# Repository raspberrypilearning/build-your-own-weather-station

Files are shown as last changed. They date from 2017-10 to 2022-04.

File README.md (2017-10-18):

# build-your-own-weather-station
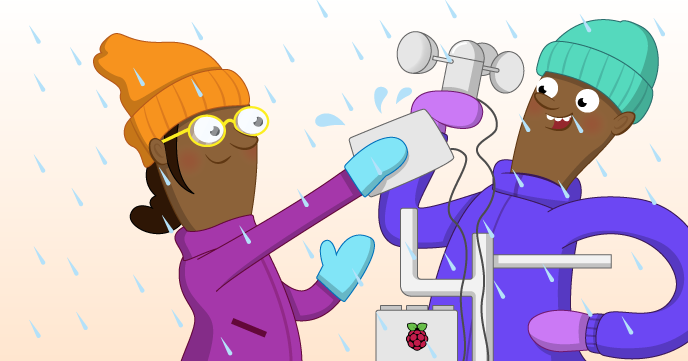
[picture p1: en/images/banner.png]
build-your-own-weather-station

Find the project online at [projects.raspberrypi.org/en/projects/build-your-own-weather-station](https://projects.raspberrypi.org/en/projects/build-your-own-weather-station)

## Contributing
See [CONTRIBUTING.md](CONTRIBUTING.md)
## Licence
 See [LICENSE.md](LICENSE.md)

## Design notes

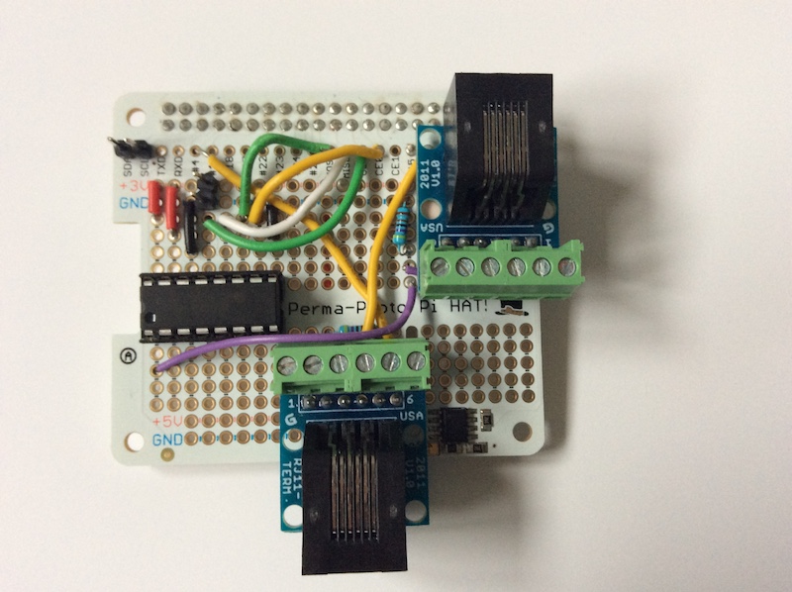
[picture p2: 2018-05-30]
en/images/BYO_HAT_front.JPG

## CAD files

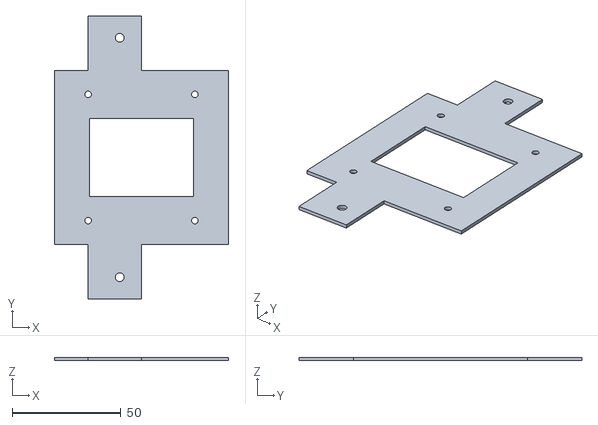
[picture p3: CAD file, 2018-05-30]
en/resources/BYOWS-bracket.stl
80.0 x 130.0 x 1.50

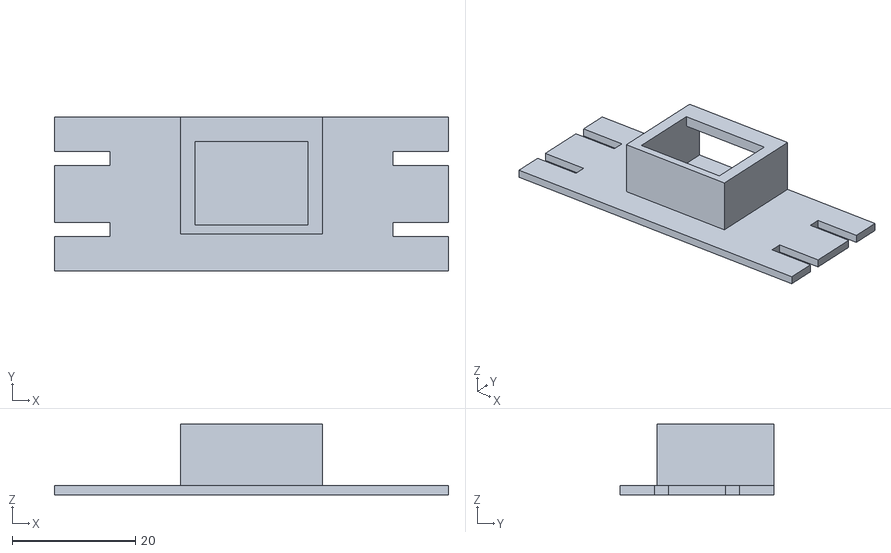
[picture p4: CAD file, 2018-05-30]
en/resources/bme280holder.stl
64.0 x 25.0 x 11.5

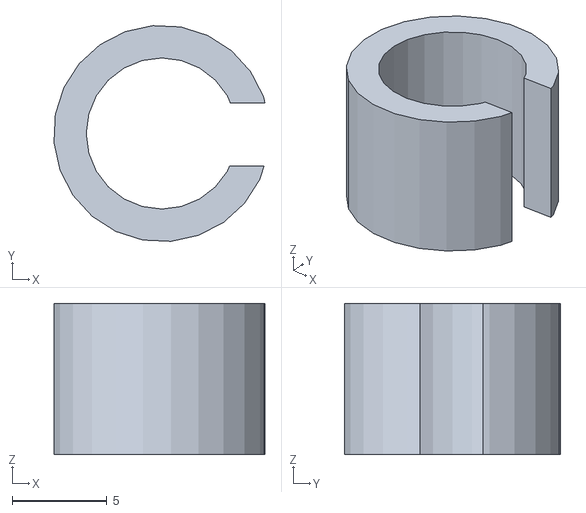
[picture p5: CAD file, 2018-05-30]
en/resources/BYOWS-grom.stl
11.1 x 11.4 x 8.00

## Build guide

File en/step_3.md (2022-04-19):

## Humidity, temperature and pressure

The BME280 sensor is a digital sensor that can measure temperature, humidity, and atmospheric pressure. It is available in a number of breakout boards from popular manufacturers such as Adafruit and SparkFun. This guide assumes you have the Adafruit package, but the instructions should be applicable to most versions. One thing to check is that the I2C address is correct: for the Adafruit models it is 0x77 (as shown in the code below), but other versions can have different addresses (0x76 is a common alternative).

### Wiring up the sensor

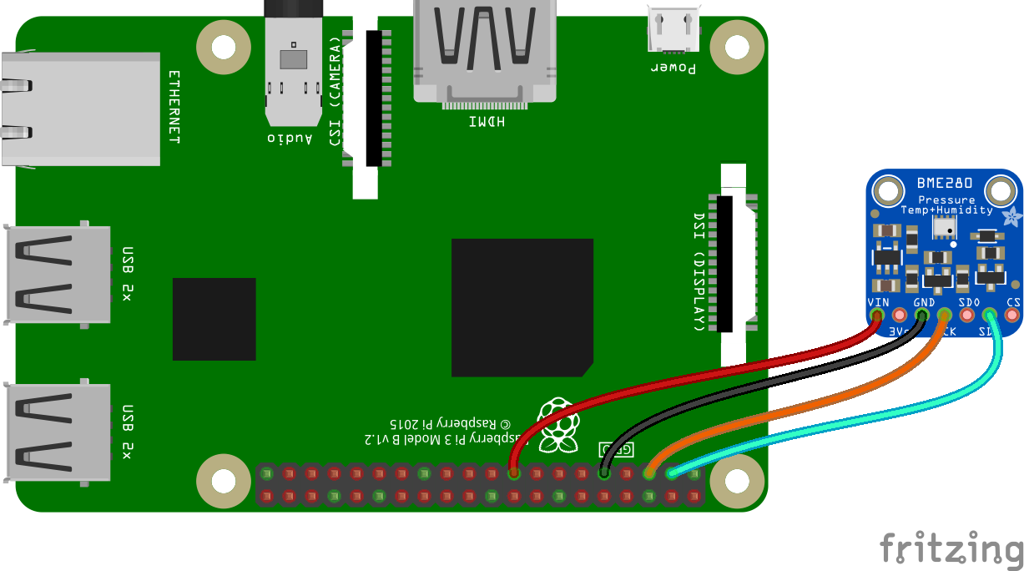
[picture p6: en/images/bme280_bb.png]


- Connect up the sensor to your Pi as shown in the diagram above.

| Pi GPIO | BME280  |
|---|---|
| 17 (3V3) | Vin |
| 6 (Gnd) | Gnd|
| 3 (SDA) | SDA (SDI) |
| 5 (SCL) | SCL (SCK)|

Some other breakout boards may have other pins (such as SDO or CSB), but those are not generally needed.

- Open IDLE.

[[[rpi-gui-idle-opening]]]

- Create a new Python file, save it as `/home/username/weather-station/bme280_sensor.py`. Replace `username` with your username on your Raspberry Pi, and add the following code to it:

```python
import bme280
import smbus2
from time import sleep

port = 1
address = 0x77 # Adafruit BME280 address. Other BME280s may be different
bus = smbus2.SMBus(port)

bme280.load_calibration_params(bus,address)

while True:
    bme280_data = bme280.sample(bus,address)
    humidity  = bme280_data.humidity
    pressure  = bme280_data.pressure
    ambient_temperature = bme280_data.temperature
    print(humidity, pressure, ambient_temperature)
    sleep(1)
```

- Now test the code: while the code is running, exhale onto the sensor. You should see the humidity values (and possibly the temperature values) increase. When you've finished testing, terminate the code by typing <kbd>ctrl+c</kbd> in the Python shell.

Once you're happy that the sensor is recording sensible values, you can go on to modify the program so that it is ready to be used as part of the whole weather station operation later.

- Replace the `while True` loop with a function called `read_all()` that returns the humidity, pressure, and temperature readings, in that order.

---hints---
---hint---
Functions are declared with the `def` keyword:

```python
def read_all():
```

---/hint---
---hint---
Add a line to sample the data from the I2C device. Then return the temperature, pressure, and humidity components of that reading.

---/hint---
---hint---
Your file should look like this:
```python
import bme280
import smbus2
from time import sleep

port = 1
address = 0x76
bus = smbus2.SMBus(port)

bme280_load_calibration_params(bus, address)

def read_all():
    bme280_data = bme.sample(bus,address)
    return bme280_data.humidity, bme280_data.pressure, bme280_data.temperature

```
---/hint---
---/hints---

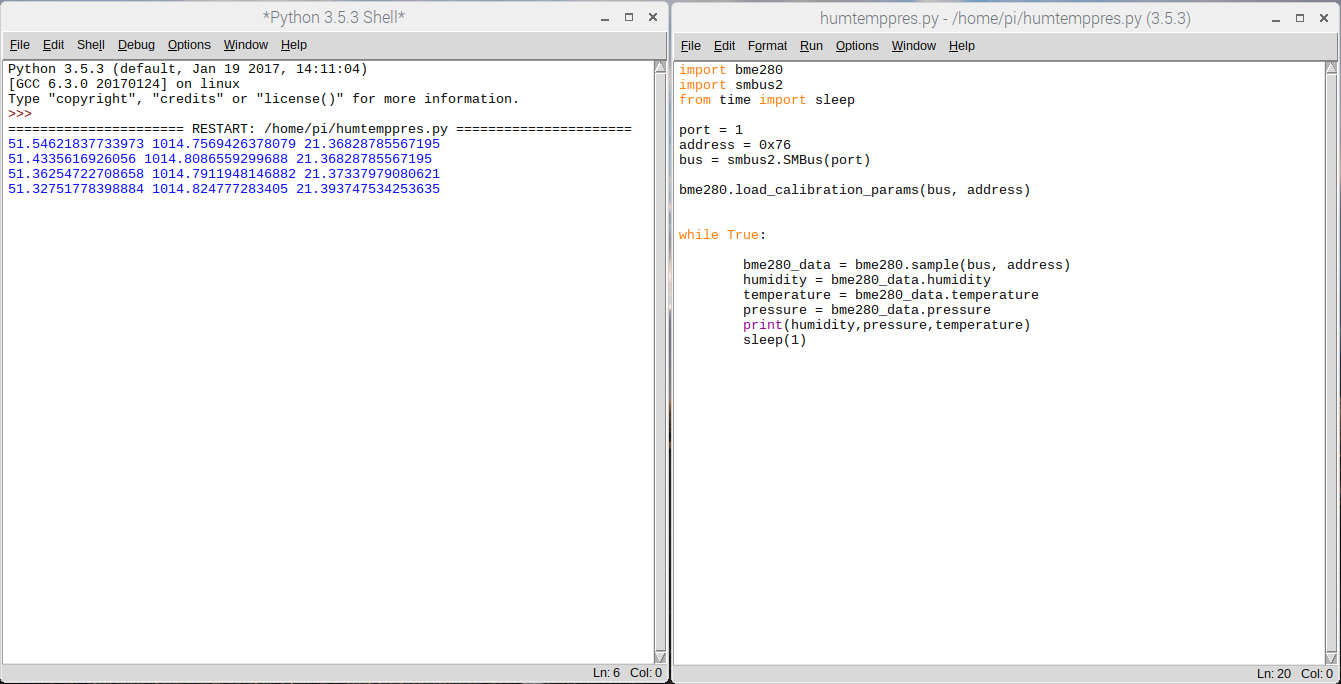
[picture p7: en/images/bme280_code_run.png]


## Ground temperature

The BME280 will report the air temperature, but this can be significantly warmer than the ground, particularly if it is frosty. A thermal probe stuck into the soil is a useful supplemental temperature measurement and can be used to indicate the presence of ice/frost in winter. The Dallas DS18B20 temperature sensor comes in many forms including a waterproof thermal probe version, and this is the sensor used on the Oracle Raspberry Pi Weather Station.

### Wiring up the sensor

- Normally the DS18B20 comes with three bare wires, so the easiest way to prototype and test the sensor is to use PCB mount screw terminal blocks that can also be plugged into breadboards. Add your DS18B20 to your circuit as shown in the diagram below. Note that you are setting up 3.3V and Ground rails along the side of the breadboard. These will be used later when you add extra sensors into the circuit.

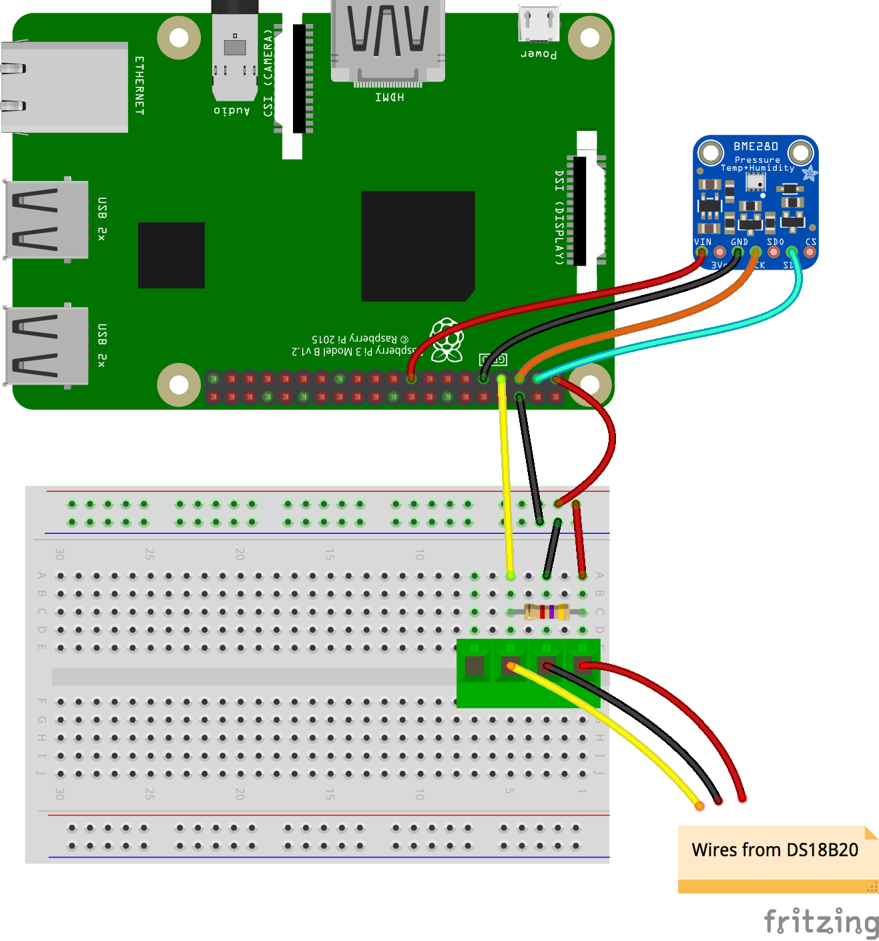
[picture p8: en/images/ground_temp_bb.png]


- Open the file `/boot/config.txt`:

```bash
sudo nano /boot/config.txt
```
 - Edit it by adding the line below at the bottom:

 ```bash
 dtoverlay=w1-gpio
 ```
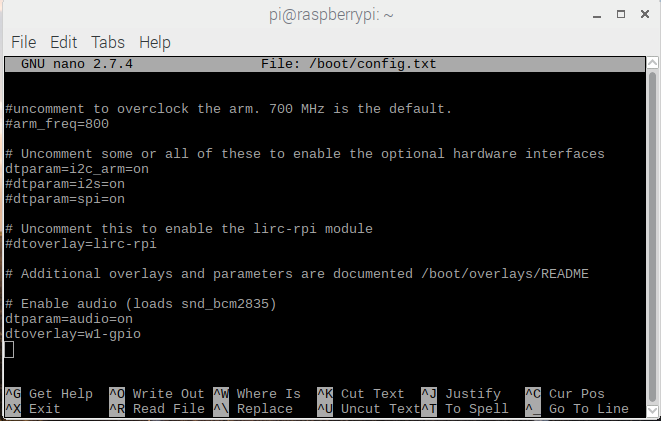
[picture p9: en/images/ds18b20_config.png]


- Then open `/etc/modules`.

```bash
sudo nano /etc/modules
```

- Add the lines below at the bottom of the file:

```bash
w1-gpio
w1-therm
```
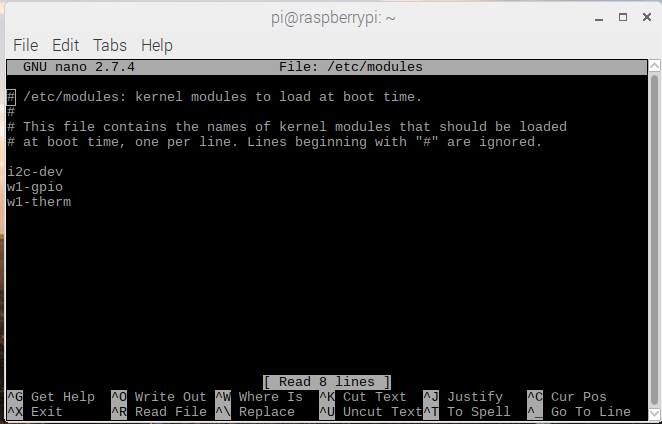
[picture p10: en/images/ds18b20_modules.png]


- Reboot the Raspberry Pi.

- Open the file `/home/pi/weather-station/ds18b20_therm.py` in IDLE and run it. You should see the temperature printed out in the Python shell window.  

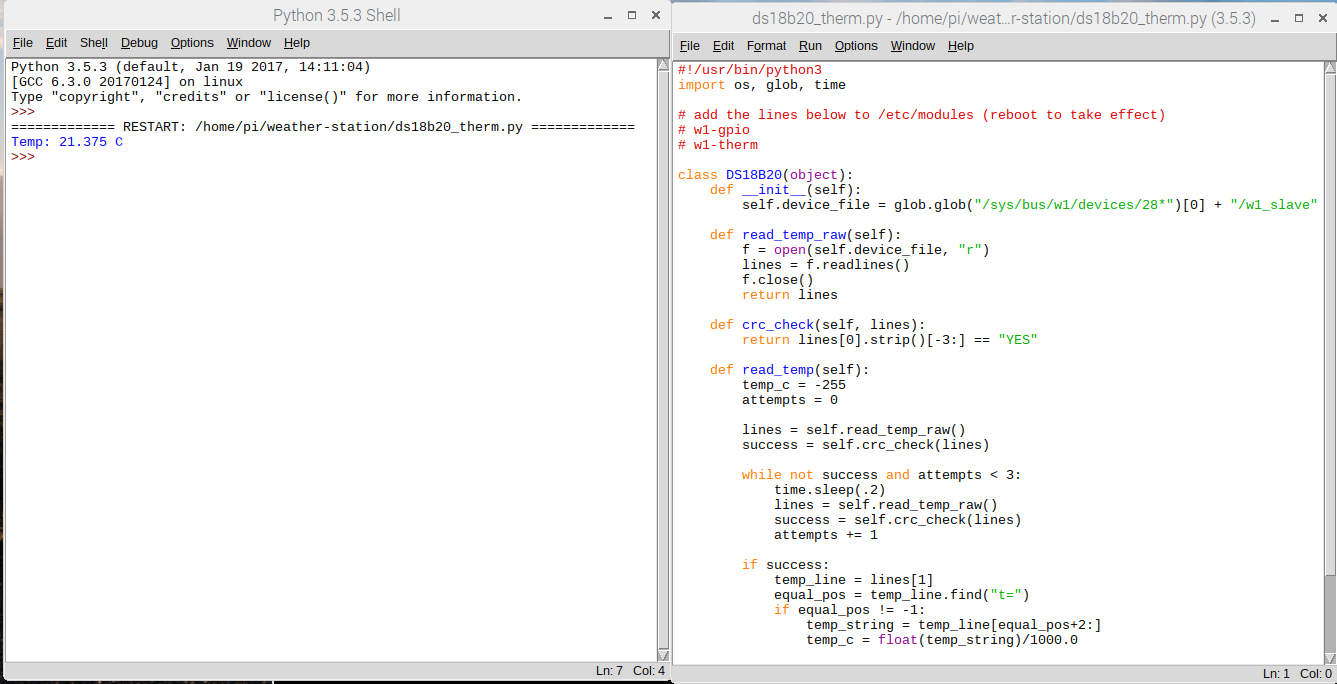
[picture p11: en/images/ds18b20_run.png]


- Put the probe into a glass of cold water and re-run the program. The new temperature reported should be lower (unless you were working in a very cold room in the first place!).

### Troubleshooting

- If you are unable to take readings from the DS18B20 sensor, check that the wires from the probe are securely connected to the screw terminals and that you have modified the `/etc/modules` and `/boot/config.txt` correctly.

+ Open a terminal window and type:

```bash
ls /sys/bus/w1/devices/
```
You should see two files listed. If these are not shown, then recheck your wiring.

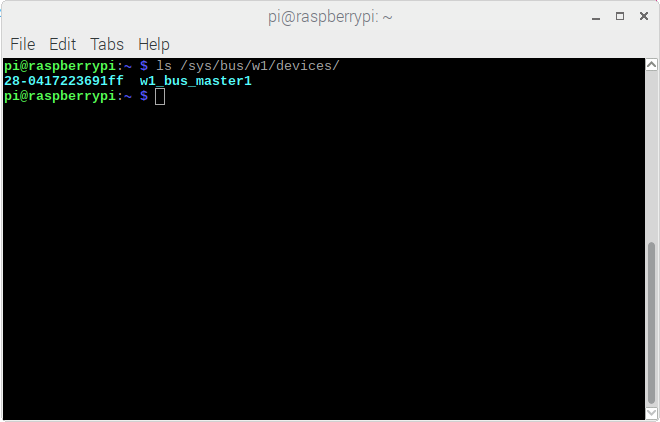
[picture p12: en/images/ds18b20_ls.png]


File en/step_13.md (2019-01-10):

## Challenge: add custom sensors
- Now you've got your weather station up and running, why not add some more sensors? You have seven free pins on the MCP3008 ADC, so you could incorporate more analog sensors!

- How about a light meter or UV sensor? How could you keep it watertight?

- Or maybe you could add a lightning detector — there are a few commercial boards available for doing this.

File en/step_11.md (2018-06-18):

## Assembling everything for outdoors

### Wireless connectivity

So that your weather station can upload data to somewhere you can view and analyse it, it will need some form of internet connection. Using WiFi is typically the easiest way to do this, but you can use the ethernet connection if that works better for your location. There's a guide about setting up wireless connectivity on your Raspberry Pi [here](https://www.raspberrypi.org/documentation/configuration/wireless/), and some special hints for getting wireless access working with a weather station are [here](https://www.raspberrypi.org/learning/weather-station-guide/outside2.md).

### Make a weather station HAT

You should now have a working weather station prototype on a breadboard. If you are happy keeping your weather station in this form, then click through to to the *Keeping your weather station dry* section.

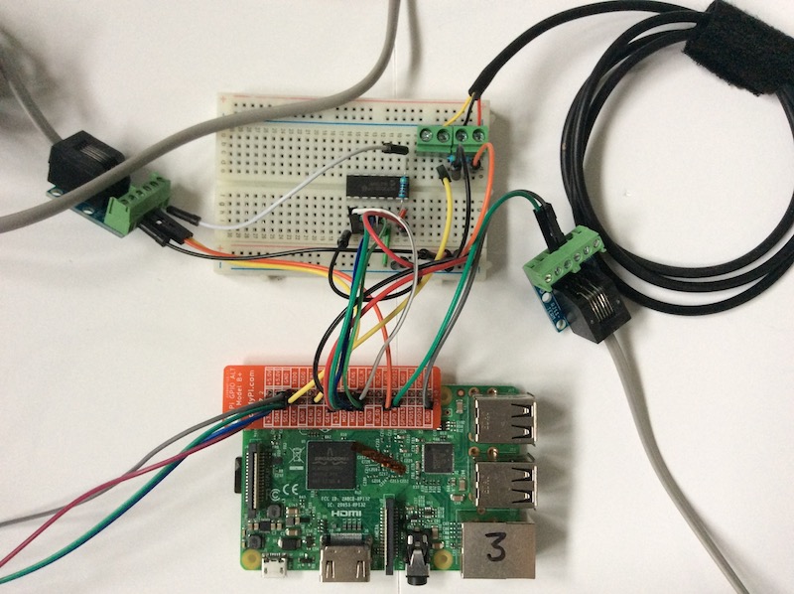
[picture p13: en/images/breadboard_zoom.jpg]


For a more robust, long-term installation, or if you don't have room for a breadboard in your enclosure, you can construct a weather station HAT (hardware attached on top) for your Pi. This will involve some soldering, and if you've never soldered before, we have a [great resource plus video tutorial](https://projects.raspberrypi.org/en/projects/getting-started-with-soldering) to get you started.

Note that to really be able to call it a HAT, your board should include a programmed EEPROM. The Adafruit Perma-Proto HAT kit does come as a variant with an EEPROM so this is definitely something you could do, although we won't cover the procedure in this guide. A good place to start is this [github repository](https://github.com/raspberrypi/hats){:target="_blank"}, or this [MagPi article](https://www.raspberrypi.org/magpi/make-your-own-hat/){:target="_blank"}.

If you are going to solder your project using the recommended components, make sure to read through all the instructions before starting. The assembly is a little tricky, and it will taken even an experienced maker two to four hours.

As usual, there is more than one way to do this this. You could design a layout for stripboard (also known as veroboard).



Soldering stripboard connections can be trickier than the 'through-hole' type you may be familiar with from assembling other digital making kits. However, prototyping HATs for Raspberry Pi are also available and these have plated through hole (PTH) connections that are much easier two work with.

The circuit diagram below shows a possible design for a weather station HAT using the Adafruit Perma-Proto HAT Kit. You can lay things out differently if you have used alternative components.

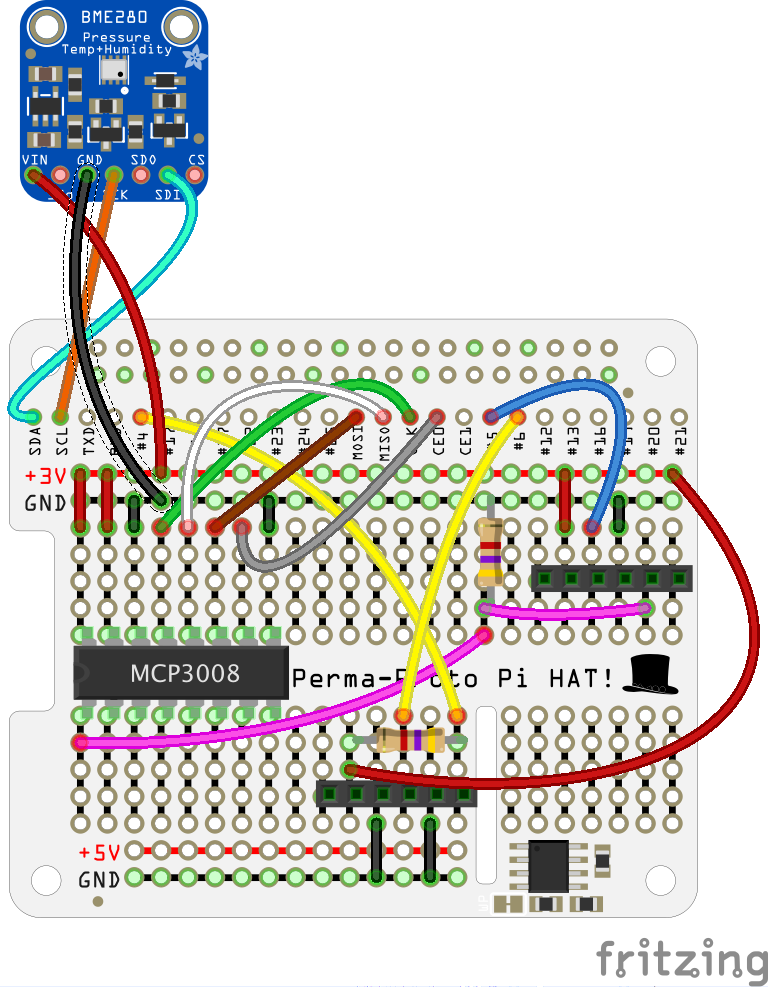
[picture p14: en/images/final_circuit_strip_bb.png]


#### Things to note about this circuit diagram

- To avoid cluttering the view, the six pins for each of the two RJ11 breakout boards are shown as female headers.

- Interpreting this diagram requires a slightly different approach to building a breadboard circuit. Because the PTH connections go all the way through the board, you can actually (and usefully) route and connect wires and components on either side.

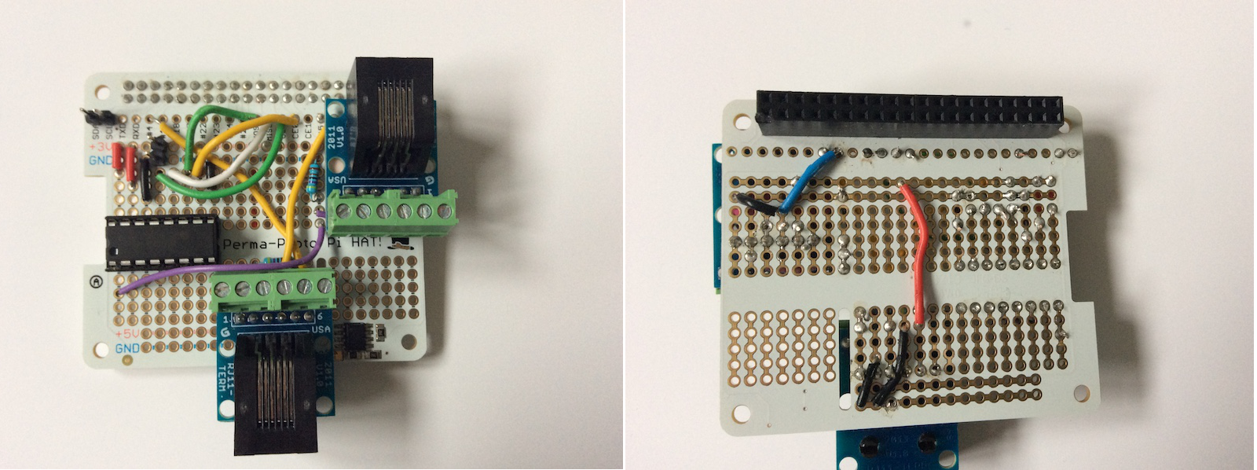
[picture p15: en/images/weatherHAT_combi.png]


In the photo above, you can see that two 2-pin male connectors have been used for the BME280 sensor. This method makes assembly easier, because the sensor should be housed in a separate enclosure. However, you could solder the wires connecting the sensor directly to the HAT (after threading them through the water-tight glands or grommets used).

## Assembly

You are recommended to assemble and test things one step at a time, checking each connection to a weather sensor once you've added it to the board.

- First of all, solder the 40-pin header onto the Adafruit board.

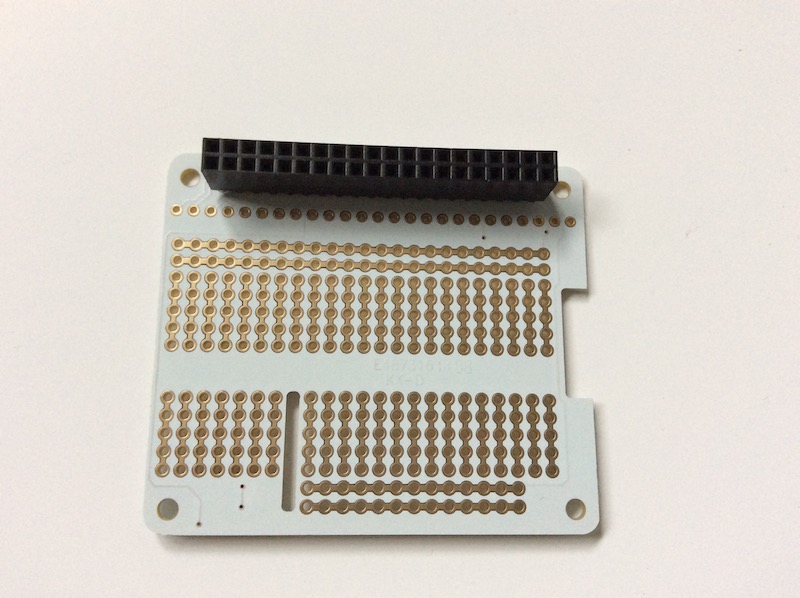
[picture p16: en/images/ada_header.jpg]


- Solder on two 2-pin male headers, one across the SCL and SDA connections in the top left-hand corner, and one across the **3V** and **GND** rails.

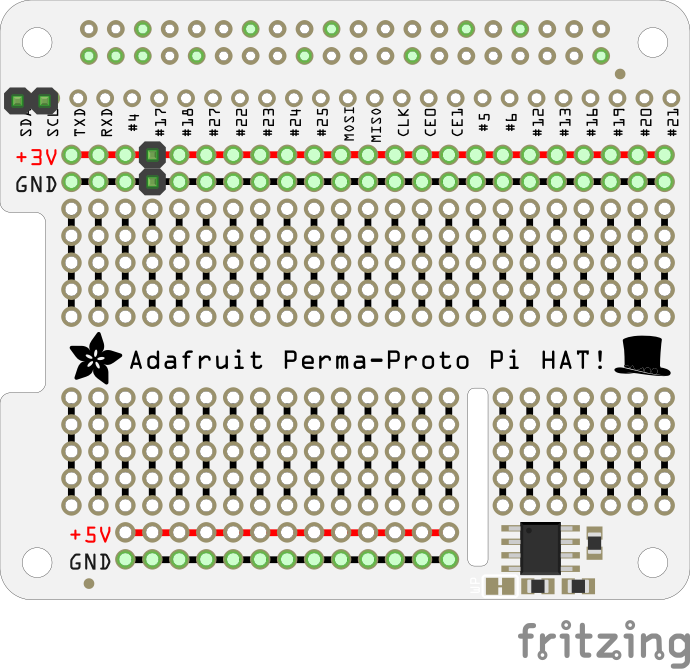
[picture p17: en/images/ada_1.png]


- Connect the BME280 sensor to these pins and place the HAT on the Pi.

- Boot the Pi and test that the BME280 sensor works using the `bme280_sensor.py` code that you wrote earlier.

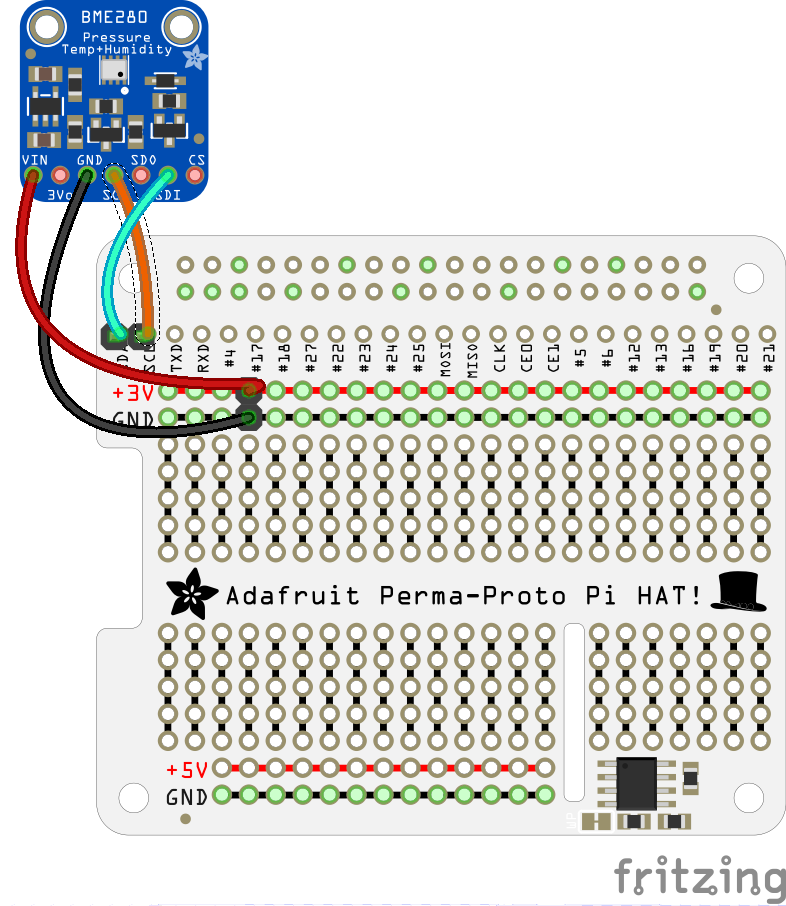
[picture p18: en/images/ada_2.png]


Next, add connections for the DS18B20 probe. On the breadboard you used screw terminals. You could use them again on the proto-board, but you may have noticed that one of the RJ11 breakout boards has some unused pins. You can be sneaky and make use of the unused screw terminals to save space: the rainfall gauge only uses the two centre pins of the connector, so the two outer ones on either side are free.

- Power down the Pi and remove the HAT.

- Solder a 4.7K ohms resistor in the bottom area as shown. Your RJ11 breakout board will need to sit just above this, so try to seat the resistor so that it is flat against the top of the Adafruit board and not poking upwards.

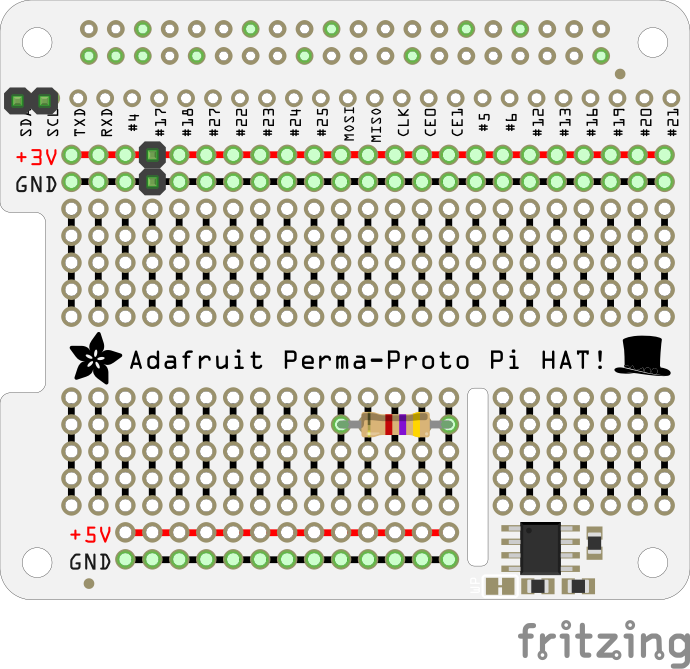
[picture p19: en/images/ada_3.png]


- Now add two connections to the bottom **GND** rail using small lengths of wire.

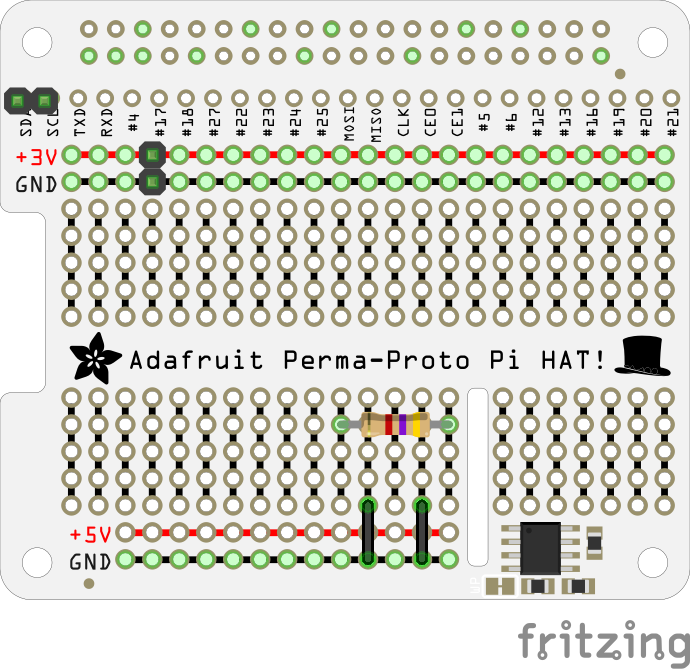
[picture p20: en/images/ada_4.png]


- Then add longer wires to connect the GPIO pin breakout connections (**GPIO 4, 6**) and the **3V** rail. Once again, try to keep these as low as possible where the RJ11 breakout board will sit. As mentioned earlier, you can solder the wires through from the bottom of the HAT rather than across the top. As long as the correct holes are connected together, it doesn't matter which side of the HAT you use.

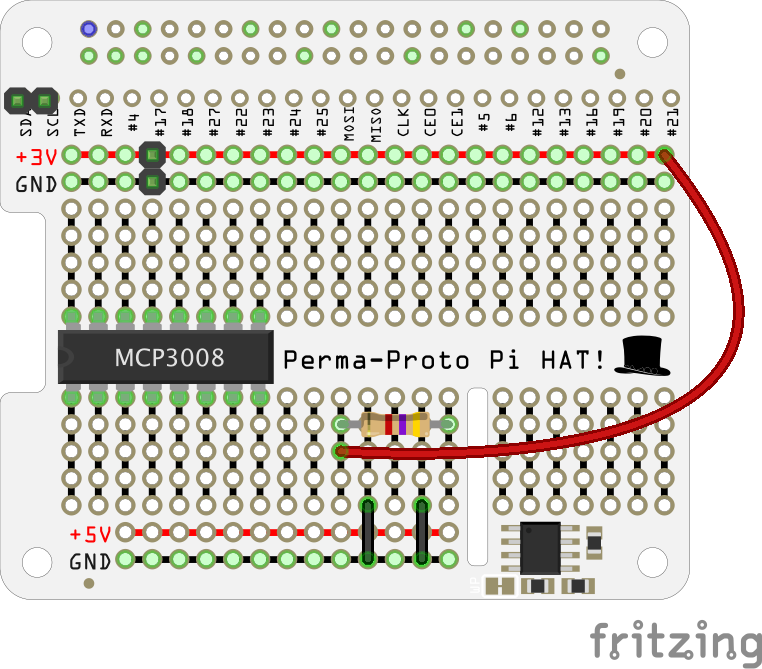
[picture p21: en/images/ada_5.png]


The connection to the **3V** rail will pass through a 'busy' part of the board if it goes over the top, so this is a good choice to put it on the rear.

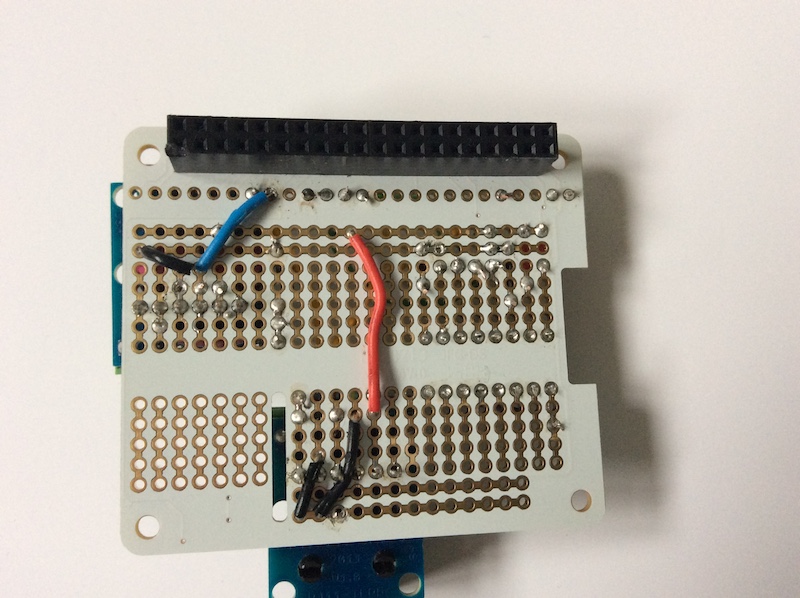
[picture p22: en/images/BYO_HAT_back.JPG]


- Now prepare the RJ11 breakout board. Some of the pre-soldered parts of these breakout boards can be quite spiky. To avoid these peaks of solder from causing shorts when placed onto the Adafruit board, carefully trim them with side cutters. It is also a good idea to then cover them with a small strip of insulating tape.

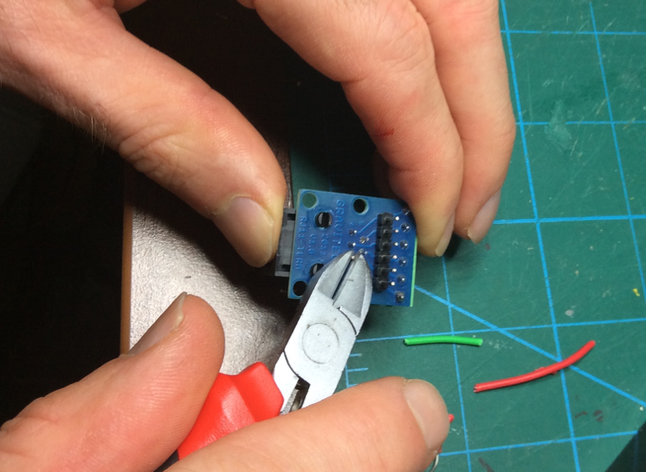
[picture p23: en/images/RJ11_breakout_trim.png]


- With some versions of the smaller boards, the male pins you need for connection to the Adafruit board are supplied separately. You may have to solder them onto the breakout board first. Make sure the shortest end of the pin is the part that you solder on, as the longer end is the part that you'll solder onto the Adafruit board.

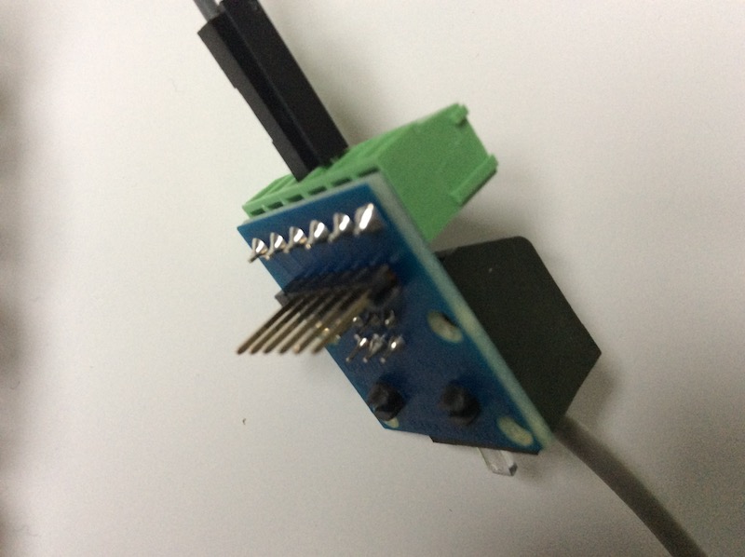
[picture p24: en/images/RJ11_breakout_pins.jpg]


- Solder the RJ11 breakout board in place, making sure that the pins slot into the correct place on the Adafruit board. Be careful not to melt the plastic on the RJ11 socket. The pins from the breakout board are quite long and will make contact with the HDMI port on the Raspberry Pi when the HAT is in place. Therefore, you should either trim them or use some insulating tape on the top of the HDMI port to prevent a short circuit.

- Connect the DS18B20 sensor to the screw terminals on the breakout board as shown below.

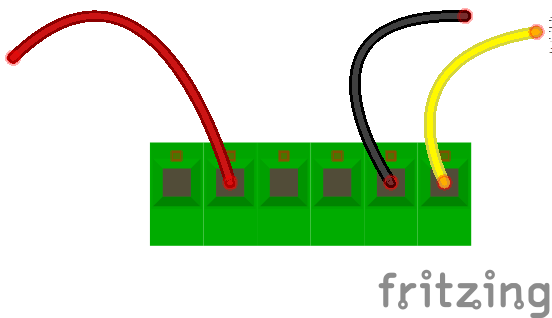
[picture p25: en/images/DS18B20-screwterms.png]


- Carefully remount the HAT on the Pi. Before powering up the Pi, check that none of the soldered connections on the bottom of the Adafruit board are touching the top components on the Pi. If they are, trim the wires or pins in question.   

- Power up the Pi and test your DS18B20 sensor using the `ds18b20_therm.py` script.

- Connect the rain gauge's RJ11 connector to your HAT.

- Test that the rain gauge works using the `rainfall.py` scripts you've written.

Now you need to add the MCP3008 ADC. While you can solder the IC directly onto the Adafruit board, it is much better to use a DIP/DIL IC socket. This reduces the chance of damage to the IC and also makes it easier to swap components out in future.

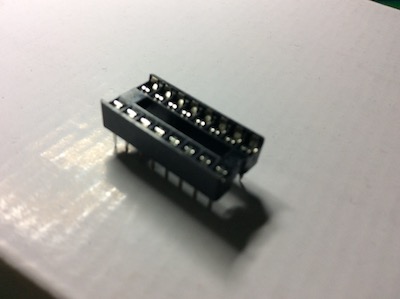
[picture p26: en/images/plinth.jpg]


- Remove the HAT and solder the socket onto the Adafruit board, in the position shown by the MCP3008 IC in the diagram.

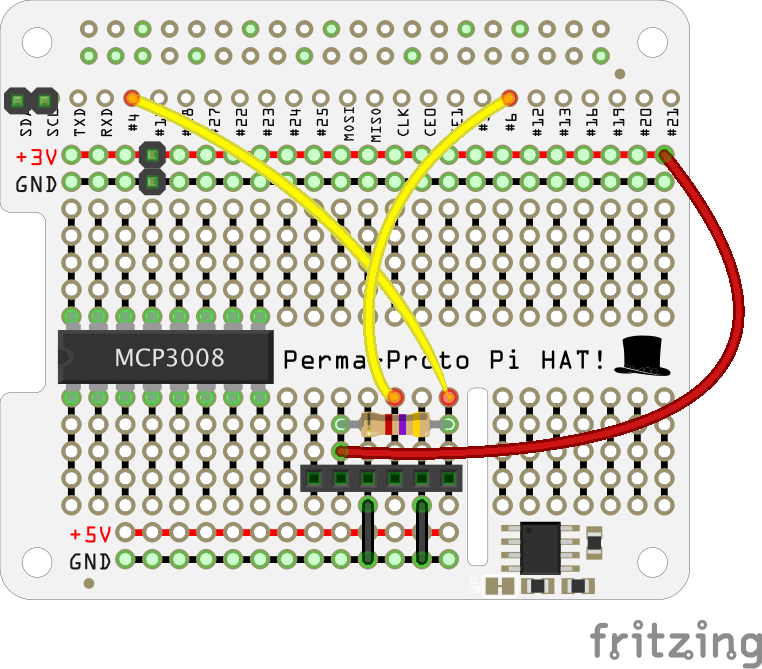
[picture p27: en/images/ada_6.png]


- Now use five short strips of wire to make connections to the **3V** and **GND** rails for the IC and the second RJ11 breakout board.

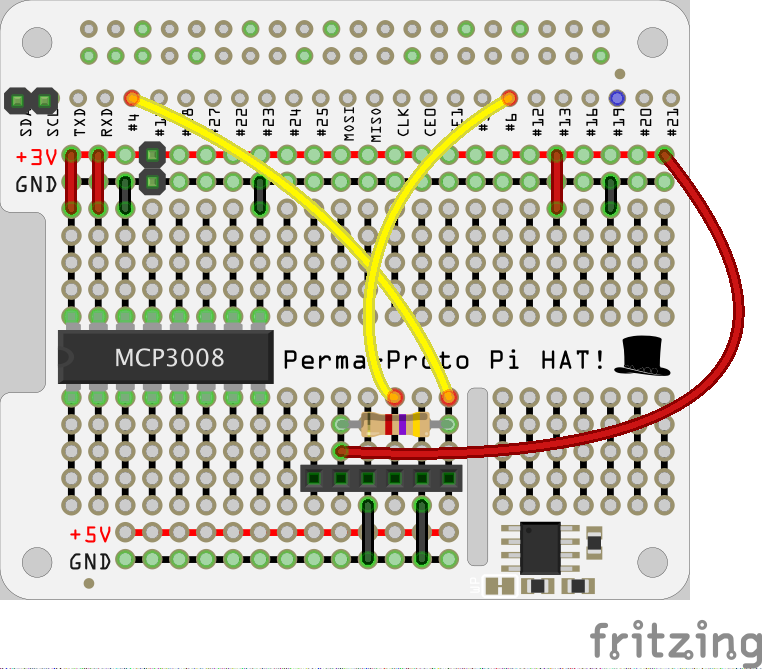
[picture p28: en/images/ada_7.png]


- Using some longer wire strips, add in the other connections to the GPIO pins. You can use either the front or the back of the board to route these connections, although soldering the GPIO ends near the black plastic of the female header on the back can be trickier than on top.

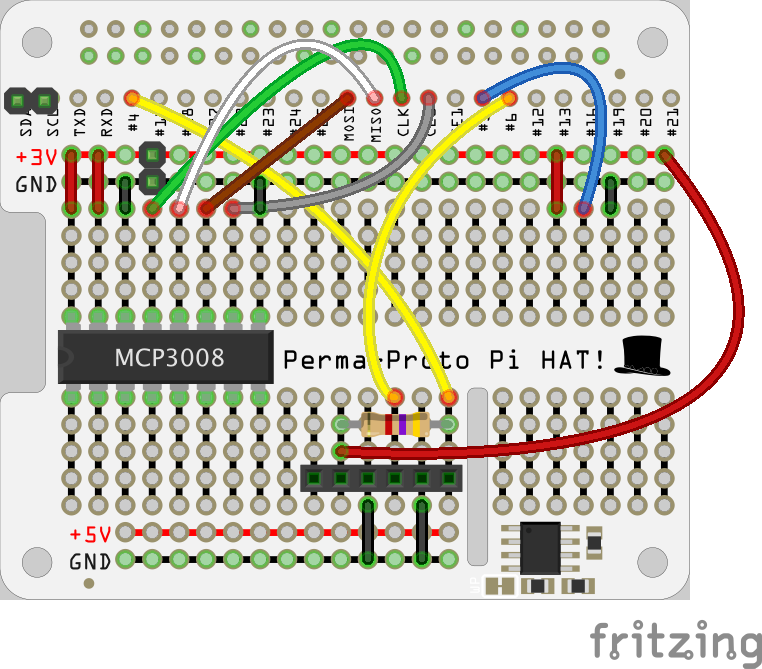
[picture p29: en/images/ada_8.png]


- Add two final wires for the wind vane part of the circuit.

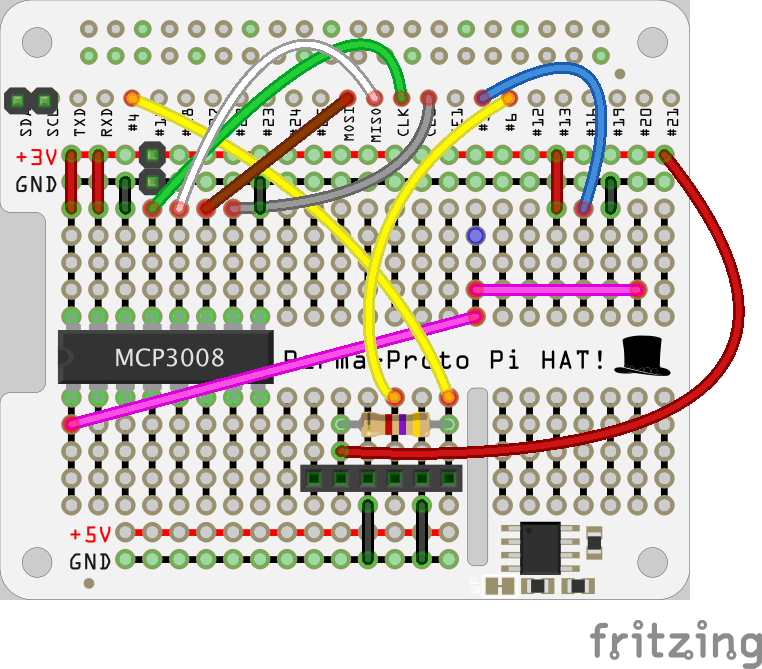
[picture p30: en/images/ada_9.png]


- Then solder on the second 4.7K ohms resistor.

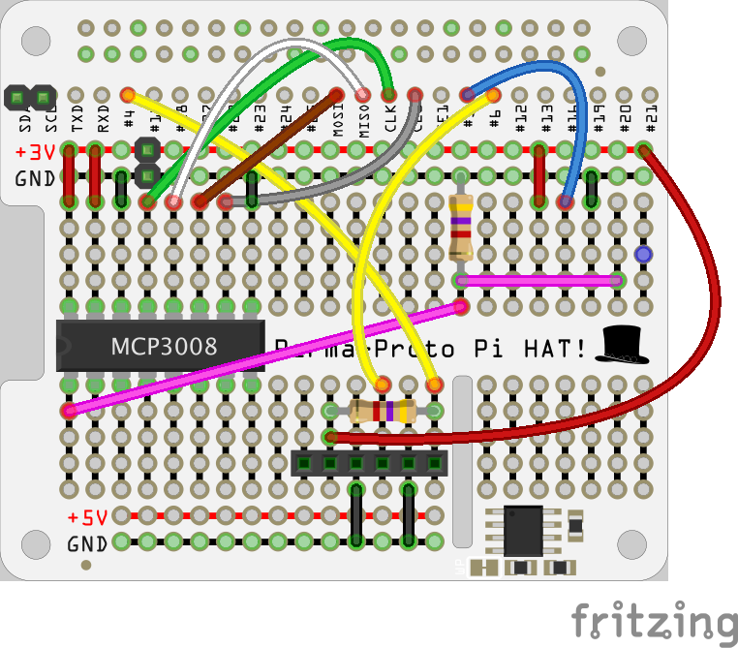
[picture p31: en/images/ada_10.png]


- The final step is to add the second RJ11 breakout board, remembering to ensure that no short circuits are caused by spiky or long pins protruding from the bottom of the board.

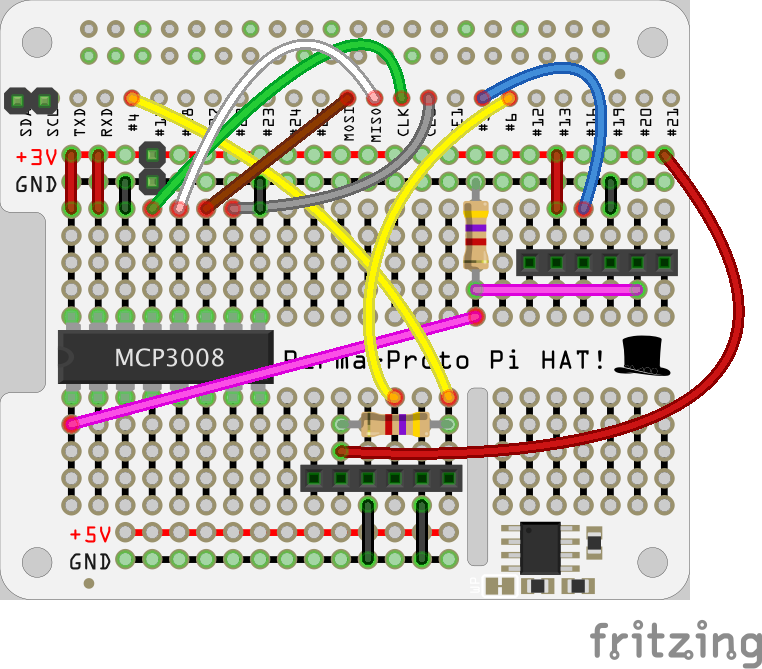
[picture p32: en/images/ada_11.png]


- Carefully insert the MP3008 IC into the socket. You may need to gently bend the legs slightly so that they fit in without being crushed under the main body of the chip itself.

- Remount the HAT on the Pi again. Check that none of the soldered connections on the bottom of the Adafruit board are touching the top components on the Pi. Trim any wires or pins if they are.

- Plug in the RJ11 connector from the wind sensors and test them using the `wind_direction_byo.py` and `wind.py` scripts you wrote.

- You should now have a fully working weather HAT. Test it for a while with the full program that you completed in the previous step.

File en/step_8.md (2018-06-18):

## Wind direction

### Wind vanes
Wind vanes show the direction the wind is coming from, not where it's going. This can be a little confusing in the beginning, because the arrows on most TV weather maps show the opposite. A wind vane works because wind exerts force on its vertical blade, which rotates to find the position of least wind resistance; this position is aligned with the direction of the oncoming wind.

### How your wind vane works
Like the rain gauge or anemometer, the wind vane used here also has reed switches and a rotating magnet, but it is more complex and works in a completely different way.

If you look inside the recommended wind vane, you'll see eight reed switches arranged like the spokes of a wheel.

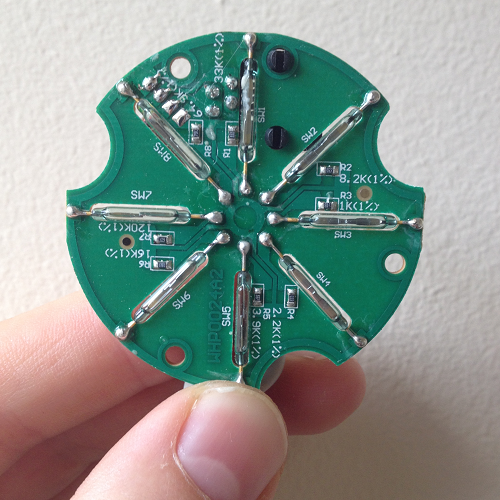
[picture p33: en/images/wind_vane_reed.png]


There are also eight **resistors** in the wind vane, and as the magnet rotates, different reed switches will open and close and thus switch their corresponding resistor in and out of the circuit.

### The role of the resistors
Resistors are small components that resist/reduce the flow of electrical current without stopping it. Resistors can have different **resistance** values, reported in ohms Ω; those with low resistance let almost all current through, while those with high resistance let very little current through. The most common uses for resistors are protecting components from being damaged by currents that are too high, or dividing voltage between different parts of a circuit.

Each of the eight resistors has a different value, which you should see printed in white next to it (e.g. you can see 8.2K on the right). This allows the wind vane to have 16 possible combinations of resistance, since the magnet can close two neigboring reed switches when it's positioned halfway between them. You can find more information in the [data sheet](https://www.argentdata.com/files/80422_datasheet.pdf).

Most wind vanes you can connect to a Pi work in a similar way, so if you have a different model, consult its data sheet to find the values for the resistors.

### Measuring the resistance
In order to read the wind direction from the vane, you'll need to be able to measure the resistance produced by the sensor and convert that into an angle value. There are several steps in this process.

Instead of measuring the resistance value directly, it is actually much easier to record a **voltage** from the wind vane that varies according to which combination of resistors is currently switched into the circuit. This means you'll be measuring an **analogue** value: the wind vane will continuously report a **range** of voltages. By contrast, the anemometer simply reports a 'HIGH' or 'LOW' voltage — all or nothing, meaning it sends a **digital** signal.

[[[generic-theory-analogue-digital]]]

### Measuring analogue voltages with a Raspberry Pi

Unlike an Arduino, which has analogue inputs, the Raspberry Pi only has digital inputs. So to be able to interpret an analogue signal, you need a special component called an analogue-to-digital convertor (ADC).

A popular and versatile ADC is the MCP3008. It is a 16-pin integrated circuit (IC) with eight analogue inputs and can easily be used with a breadboard. It is a 10-bit ADC, meaning it has 2^10 = 1024 possible output values: e.g. for a reference voltage of 5V, the smallest change in voltage that the MCP3008 can detect is 5V/1024 = 4.88mV.

Now you can measure a changing analog signal using the MCP3008, you can use another clever circuit to produce a voltage that varies with the resistance of the wind vane.

### Using a voltage divider

Voltage dividers are among the most fundamental circuits in electronics, and they're used to reduce a large voltage into a smaller one.  

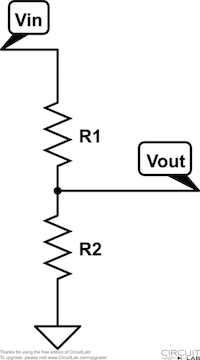
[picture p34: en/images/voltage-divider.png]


In the circuit above, the output voltage `Vout` can be calculated using the formula:

**`Vout = Vin * R2/(R1 + R2)`**

So by varying the values of `R1` and `R2`, you can reduce the input voltage `Vin` down to the output voltage `Vout`.

- Use this formula to create a new Python program called `voltage-divider.py` that contains a function `voltage_divider` that calculates `Vout` for a given set of `R1`, `R2`, and `Vin`.

---hints---
---hint---
To start off, create a function definition that takes the three input values:

```python
def voltage_divider(r1, r2, vin):
```
---/hint---
---hint---

Then add the formula.

```python
vout = (vin* r1)/(r1+r2)

```
---/hint---
---hint---

Finally, include a `return` statement. To make things easier to read, round the answer to three decimal places.
```python
def voltage_divider(r1,r2,vin):
    vout = (vin* r1)/(r1+r2)
    return round(vout,3)
```
---/hint---
---/hints---

- Test your function to make sure it provides the right answer for a selection of input values. For example, when `R1 = 33K ohms, R2 = 10K ohms` and a reference voltage of `Vin = 5V`, the function should return an answer of `3.837V`.

```python
print(voltage_divider(33000,10000,5.0))
```

Now returning to the circuit, if you imagine that `R2` is actually the resistance of some kind of variable resistor (a light-dependent resistor, for example), then by measuring `Vout`, we can calculate `R2` as long as we know `R1`. The wind vane acts like a variable resistor, so you can use a voltage divider circuit to measure its resistance value at any given time.

First of all, you need to find the best value for `R1` to use.

### Designing a voltage divider

You may have noticed that the second page of the wind vane data sheet contains a voltage divider circuit diagram and a table that lists angle, resistance, and voltage. The value quoted for `R1` in this diagram is 10K ohms. However, this circuit uses a `Vin` reference voltage of 5V. The logic levels on a Raspberry Pi are 3.3V, so these `Vout` figures are not quite right for what you need.

- Using the list of resistances from the datasheet and the voltage divider formula, write a small Python program called `vane_values.py` to calculate the new values for a 3.3V `Vin` with a `R1` resistance of 10K ohms.

---hints---
---hint---
To start off, create a list that contains all the resistances of the vane:

```python
resistances = [33000, 6570, 8200, 891,
               1000, 688, 2200, 1410,
               3900, 3140, 16000, 14120,
               120000, 42120, 64900, 21880]
```
Then loop through this list, calculating the output voltage for each value. You can use the `voltage_divider` function you wrote earlier for this part.  
---/hint---
---hint---

To loop through the list and print out each value, you could use the code:

```python

for x in range(len(resistances)):
    print(resistance[x])
```
This can be expanded to include the calculation too.
---/hint---
---hint---

A complete solution, including rounding the values to three decimal places, is:
```python
resistances = [33000, 6570, 8200, 891,
               1000, 688, 2200, 1410,
               3900, 3140, 16000, 14120,
               120000, 42120, 64900, 21880]

def voltage_divider(r1,r2,vin):
    vout = (vin* r1)/(r1+r2)
    return round(vout,3)

for x in range(len(resistances)):
    print(resistances[x],voltage_divider(10000,resistances[x],3.3))
```
---/hint---
---/hints---

Using the value of `R1 = 10K ohms` works well when the reference voltage is 5V, but you should see that some of the possible voltages are quite close together when using 3.3V. By using a smaller value for R1, you can optimise the separation between the different voltages that correspond to the resistance values produced by the vane.

- Use your `vane_values.py` code to test alternative values for `R1`. Remember that only certain standard resistance values are available.

The most common in the range you'll need are (in K ohms):
+ 1
+ 1.2
+ 1.5
+ 1.8
+ 2.2
+ 2.7
+ 3.3
+ 4.7
+ 5.6
+ 6.8
+ 8.2

You should find that 4.7K ohms is a good value for the recommended wind vane.

- Now you know the value for `R1` in the voltage divider circuit, you can wire everything up to your ADC and the Pi.

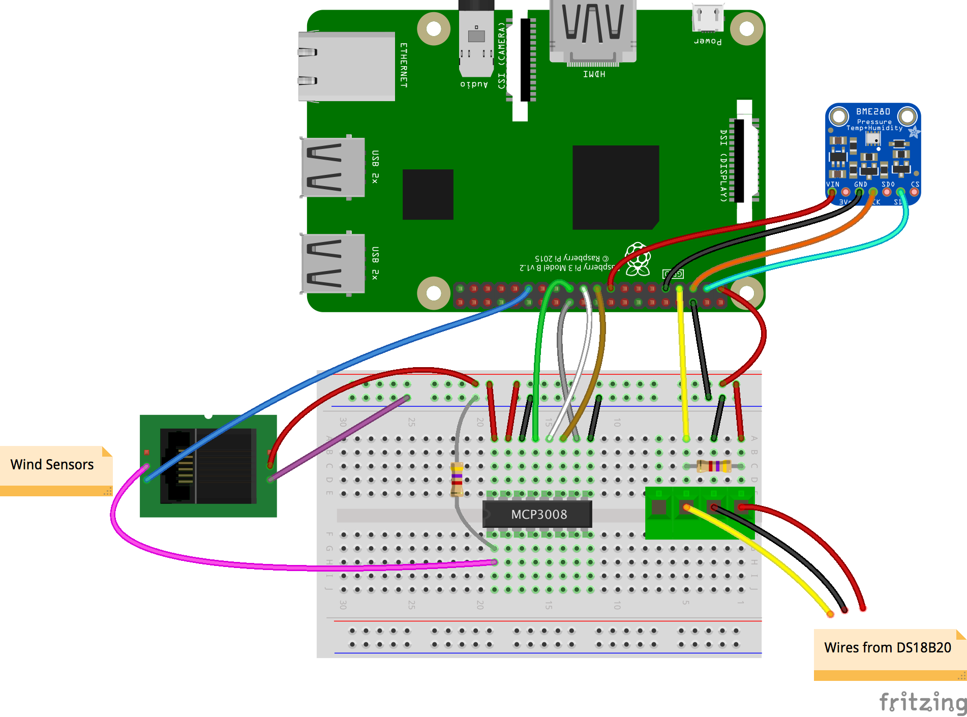
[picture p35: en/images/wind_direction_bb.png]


Reading values from an MCP3008 ADC is very easy, thanks to the `gpiozero` library.

```Python
from gpiozero import MCP3008
import time
adc = MCP3008(channel=0)

print(adc.value)
```
This code will read channel 0 of the ADC and print its value scaled to between 0 and 1. To find the actual analog voltage that's recorded, multiply the value by the reference voltage supplied to the ADC.

- You need to test that your circuit is able to discriminate between the various angular positions of the wind vane. Create a small python program called `/home/pi/weather-station/wind_direction_byo.py` to count the different values produced by your circuit when the vane is rotated.  

---hints---
---hint---
Use the `gpiozero` library to create a MCP3008 instance:

```Python
from gpiozero import MCP3008
import time
adc = MCP3008(channel=0)
```

---/hint---
---hint---

Then create a list to hold all the values:

```python
values = []
```
Then add a loop to repeatedly read voltages from the ADC and add the read values to the list **if they aren't already present in it**.
---/hint---
---hint---

A complete solution is:
```Python
from gpiozero import MCP3008
import time
adc = MCP3008(channel=0)
count = 0
values = []
while True:
    wind =round(adc.value*3.3,1)
    if not wind in values:
        values.append(wind)
        count+=1
        print(count)
```
---/hint---
---/hints---

- Run your code while rotating the wind vane. Your should see the number of unique voltages seen so far printed out in the Python shell.

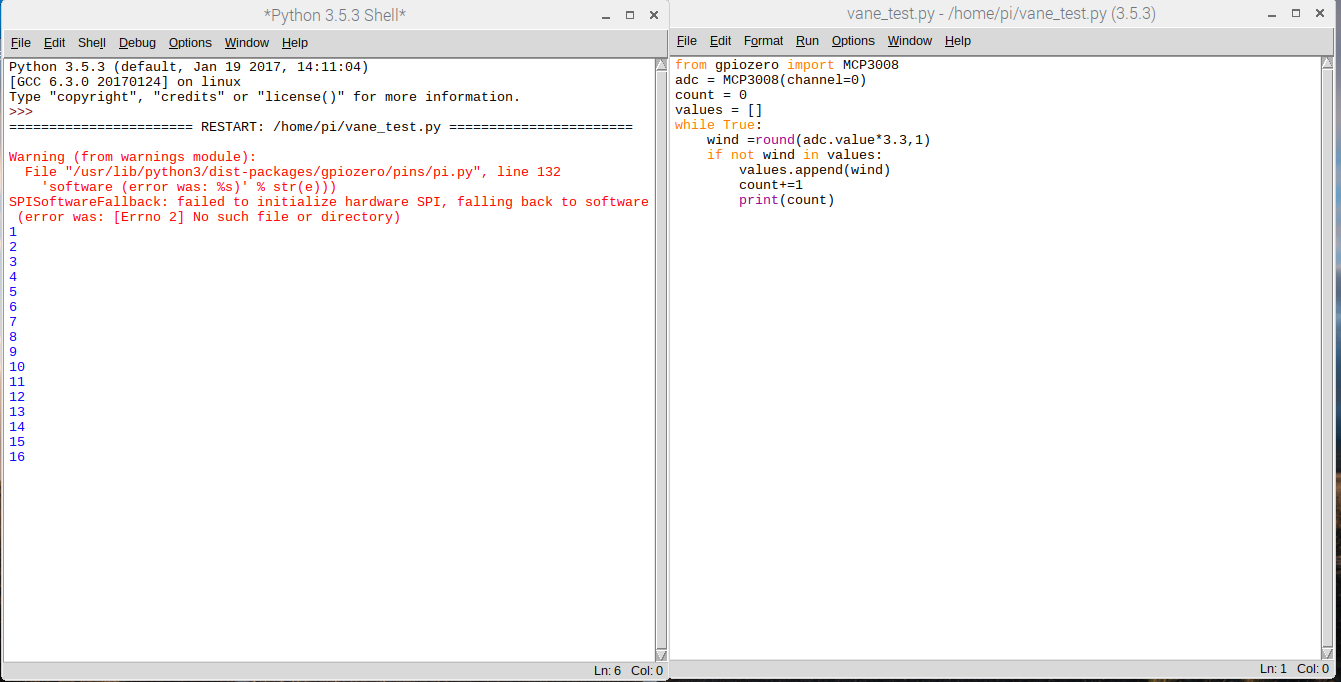
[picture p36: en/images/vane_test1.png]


- You may also see some red text warning you about 'SPISoftwareFallback'. You can safely ignore this, but if you'd rather not have the warning appear again in future, click on the Raspberry Pi menu icon and select **Preferences > Raspberry Pi Configuration**. Then enable **SPI** in the Interfaces tab, and reboot your Pi.

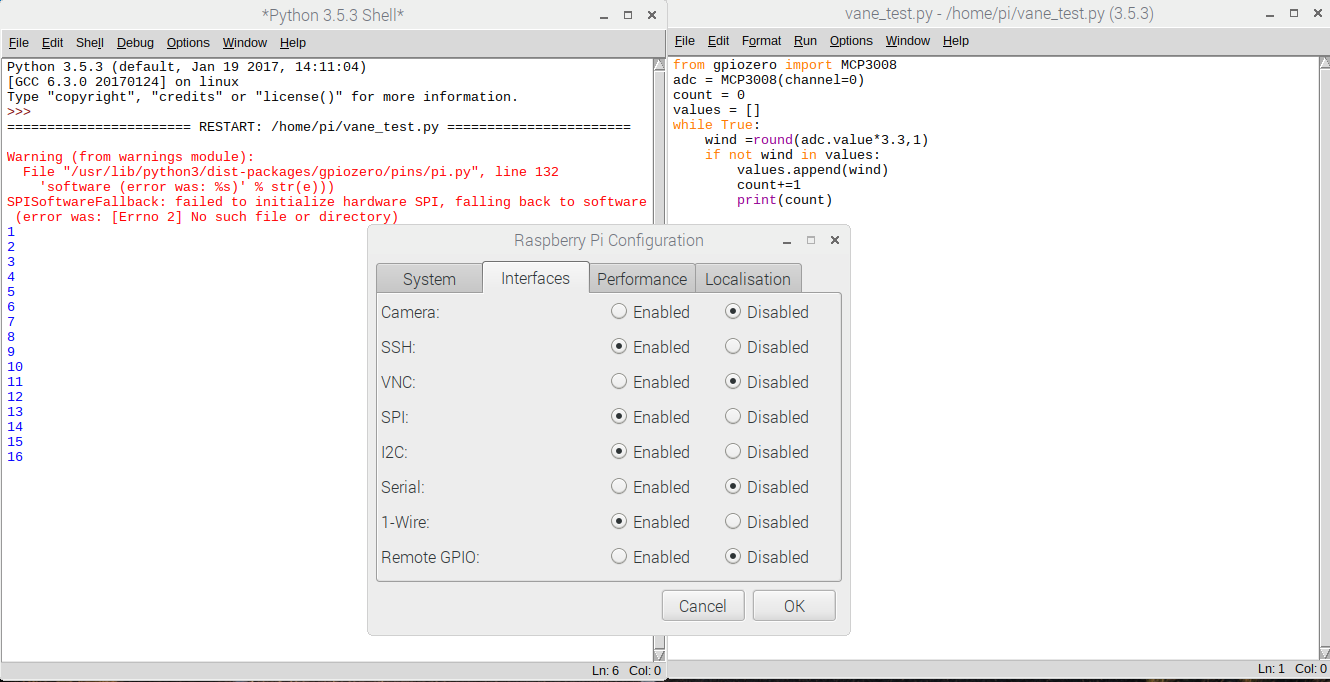
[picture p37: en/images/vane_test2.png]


- If everything is accurate to a very high level of precision, then you should be able to measure no more than 16 unique voltages. However because the ADC may record a rising or falling voltage, you may be able to generate a few more values through slow jiggling of the vane.  

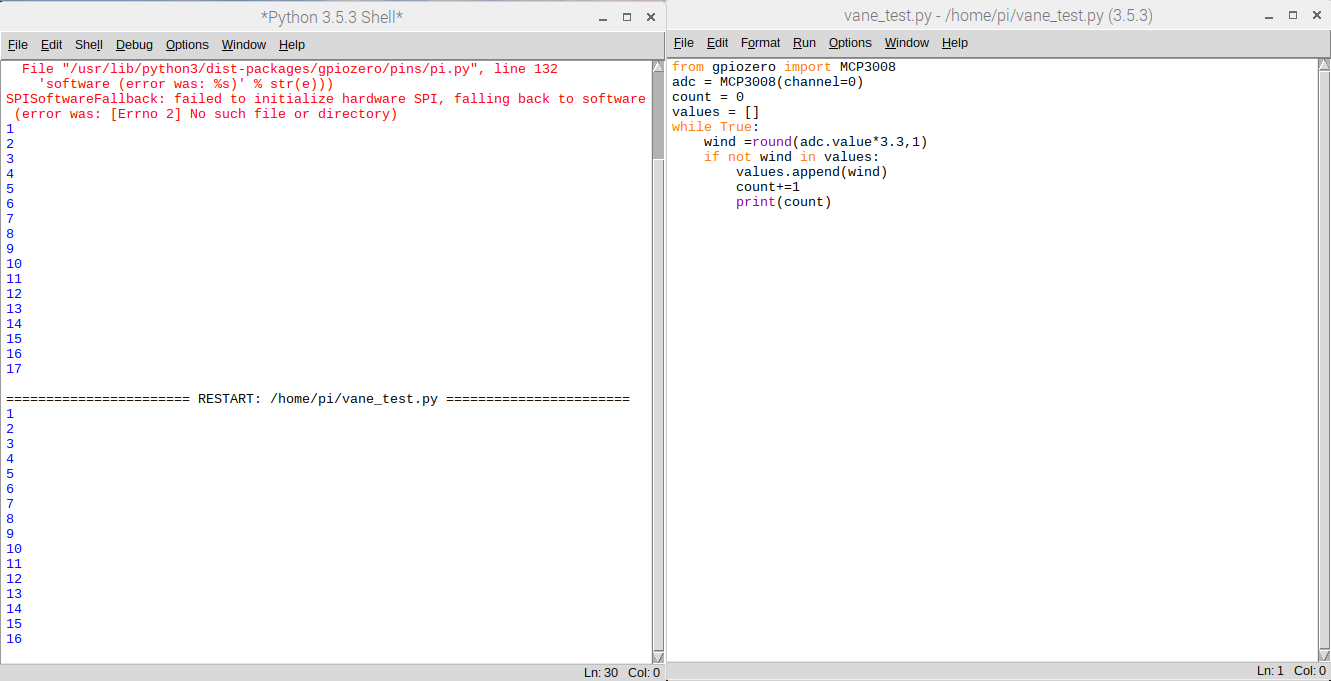
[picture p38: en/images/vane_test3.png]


- Modify your code to include a list of the possible correct values and check each reading from the ADC against this list. Have your code print a helpful message for each reading that indicates whether it was one of the correct values or not.

---hints---
---hint---
Add a list of possible values, all rounded to one decimal place. You can use your `voltage_divider` code to produce this list.

```Python
volts = [0.4, 1.4, 1.2, 2.8,
         2.9, 2.2, 2.5, 1.8,
         2.0, 0.7, 0.8, 0.1,
         0.3, 0.2, 0.6, 2.7]
```

---/hint---
---hint---

Then use an `if...else` conditional statement to test if the value from the ADC is in the `volts` list.
---/hint---
---hint---

A complete solution is:
```Python
from gpiozero import MCP3008
import time
adc = MCP3008(channel=0)
count = 0
volts = [0.4, 1.4, 1.2, 2.8,
         2.9, 2.2, 2.5, 1.8,
         2.0, 0.7, 0.8, 0.1,
         0.3, 0.2, 0.6, 2.7]
while True:
    wind =round(adc.value*3.3,1)
    if not wind in volts:
        print('Unknown value: ' + str(wind))
    else:
        print('Match: ' + str(wind))
```
---/hint---
---/hints---

The final step is to convert the readings from the vane into angles. At the heart of this is relationship between angle, resistance, and voltage. For every voltage value measured by the ADC, there is a corresponding resistance configuration of the wind vane, which in turn corresponds to the angle the vane's blade is at.

You can calculate the relationship between resistance and voltage using the `voltage_divider` function you wrote earlier. You can then look up the corresponding angle from the data sheet. So for example, if the ADC measures aa voltage of 0.4V, this corresponds to a resistance of 3.3K ohms, which maps to an angle of 0 (or 360) degrees.

- Modify your `wind_direction_byo.py` file and change your list of voltages into a Python **dictionary**: the voltages will be the **keys** and the corresponding angles will be the **values**.

[[[generic-python-key-value-pairs]]]

- Then change your `print` statements so that they display the angle of the vane.

---hints---
---hint---
Use the `voltage_divider` function to print the voltages and their corresponding resistance values. Then use the data sheet to look up the angles that map to those resistances.

---/hint---
---hint---
Your dictionary should look like this:
```python
volts = {0.4: 0.0,
         1.4: 22.5,
         1.2: 45.0,
         2.8: 67.5,
         2.7: 90.0,
         2.9: 112.5,
         2.2: 135.0,
         2.5: 157.5,
         1.8: 180.0,
         2.0: 202.5,
         0.7: 225.0,
         0.8: 247.5,
         0.1: 270.0,
         0.3: 292.5,
         0.2: 315.0,
         0.6: 337.5}
```
---/hint---
---hint---

A complete solution is:
```Python
from gpiozero import MCP3008
import time
adc = MCP3008(channel=0)
count = 0
values = []
volts = {0.4: 0.0,
         1.4: 22.5,
         1.2: 45.0,
         2.8: 67.5,
         2.7: 90.0,
         2.9: 112.5,
         2.2: 135.0,
         2.5: 157.5,
         1.8: 180.0,
         2.0: 202.5,
         0.7: 225.0,
         0.8: 247.5,
         0.1: 270.0,
         0.3: 292.5,
         0.2: 315.0,
         0.6: 337.5}
while True:
    wind =round(adc.value*3.3,1)
    if not wind in volts:
        print('unknown value ' + str(wind) + ' ' + str(volts[wind]))
    else:
        print('found ' + str(wind) + ' ' + str(volts[wind]))
```
---/hint---
---/hints---

You now have a Python program that reads the angle of the wind vane!

+ Test it by setting the wind vane into a certain position and checking that the code displays the correct value. Repeat for different positions.  

There is one last improvement you can make to the accuracy of your results, and that is to take multiple readings over a short period of time and then calculate the average value. The maths behind this is more complicated that you might think — you can read about it in detail [here](http://en.wikipedia.org/wiki/Directional_statistics){:target="_blank"}.

- Add the function below to your `wind_direction_byo.py` code.

```python
def get_average(angles):
    sin_sum = 0.0
    cos_sum = 0.0

    for angle in angles:
        r = math.radians(angle)
        sin_sum += math.sin(r)
        cos_sum += math.cos(r)

    flen = float(len(angles))
    s = sin_sum / flen
    c = cos_sum / flen
    arc = math.degrees(math.atan(s / c))
    average = 0.0

    if s > 0 and c > 0:
        average = arc
    elif c < 0:
        average = arc + 180
    elif s < 0 and c > 0:
        average = arc + 360

    return 0.0 if average == 360 else average
```
- To use it, you'll also need to import the `math` library by adding this line to the top of your file.

```python
import math
```

- Now, using a similar technique to how you checked for wind gusts in the previous step, modify your program so that in has a function `get_value()` that returns the average value for a given time period. This will make it easy to call this function from within your complete weather station code.

---hints---
---hint---

Store a number of wind direction values in a list, then use the `get_average()` function to calculate the average.

---/hint---
---hint---

You can use the `time.time()` function to accurately record values for a given time period.
---/hint---
---hint---

A complete solution is:

```Python
def get_value(length=5):
    data = []
    print("Measuring wind direction for %d seconds..." % length)
    start_time = time.time()

    while time.time() - start_time <= length:
        wind =round(adc.value*3.3,1)
        if not wind in volts: # keep only good measurements
            print('unknown value ' + str(wind))
        else:
            data.append(volts[wind])

    return get_average(data)
```
---/hint---
---/hints---

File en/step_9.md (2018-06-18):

## Rainfall

Most rain gauges measure precipitation in millimeters in height collected on one square metre during a certain time period.

The recommended rain gauge sensor supplied with the Raspberry Pi Weather Station kit is actually a simple mechanical device.

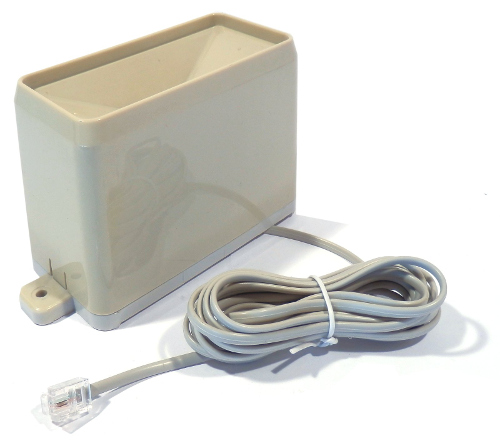
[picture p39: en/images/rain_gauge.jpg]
Rain Gauge


## How does it work?

You can investigate the rain gauge and how it works by removing the bucket. Gently squeeze the clips on either side; the lid should then pop off.

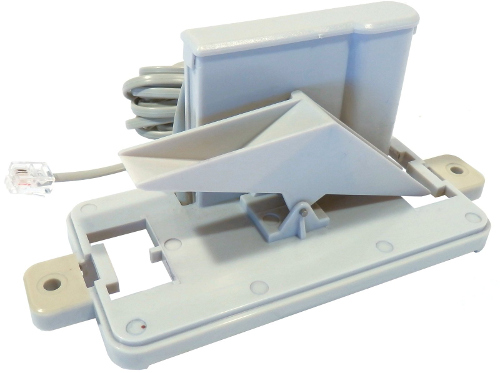
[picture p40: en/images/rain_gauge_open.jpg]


This rain gauge is basically a self-emptying tipping bucket. Rain is collected and channelled into the bucket. Once enough rainwater has been collected, the bucket will tip over, the water will drain out from the base, and the opposite bucket will come up into position.

The product [data sheet](https://www.argentdata.com/files/80422_datasheet.pdf){:target="_blank"} tells us that 0.2794 mm of rain will tip the bucket. You can multiply this by the number of tips to calculate the amount of rainfall. If you're using a different type of rain gauge, then you should consult the relevant data sheet or determine the volume of water required experimentally.

Typically these gauges are fitted with an RJ11 plug even though they only use two wires: one red and one green. Inside the ridge between the two buckets, you should see a small cylindrical magnet that points towards the back wall. Inside the back wall there's a *reed switch*.

The top of the back wall does come off if you want to see inside; just pull on the flat end gently and it should release. Inside there's a small circuit board that you can remove to examine. In the middle of it you will see the reed switch. Replace the circuit board and back wall lid before continuing.

When one of the buckets tips, the magnet passes the reed switch, causing it to close momentarily. So, just like with the anemometer, if you connect the rain gauge to a GPIO pin on the Raspberry Pi, you can treat it like a button and count the number of 'presses' to calculate rainfall.

## Connecting your rain sensor

- To test the rain gauge, you'll need to either remove the RJ11 connector and strip the wires, or make use of an RJ11 breakout board.

The Oracle Weather Station rain gauge is connected to **GPIO pin 6** (BCM), so for consistency, use the same pin for your device.

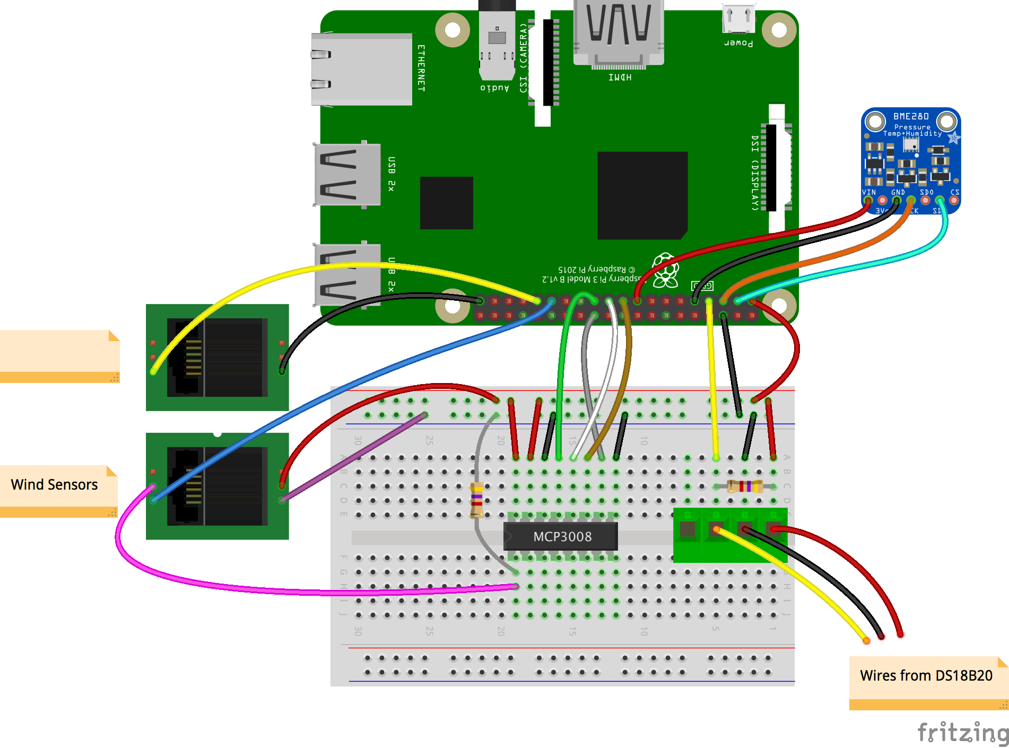
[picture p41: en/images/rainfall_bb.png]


- Using the code you wrote for the anemometer as a starting point, write a program called `/home/pi/weather-station/rainfall.py` to detect when the rain gauge bucket has tipped. It should print our a running count of how many bucket tips have occurred.

---hints---
---hint---
The `gpiozero` library provides an easy way to access button-like devices, and your bucket is connected to **GPIO 6**:

```python
from gpiozero import button
rain_sensor = Button(6)
```

---/hint---
---hint---
Create a function that is run whenever there's a bucket tip. You can assign a global variable as a counter to keep track of how many times the reed switch has been 'pressed'.
```python
def bucket_tipped():
    global count
    count = +=1
    print(count)
```
---/hint---
---hint---
Your program could look like this:

```python
from gpiozero import Button

rain_sensor = Button(6)
count = 0

def bucket_tipped():
    global count
    count = +=1
    print(count)

rain_sensor.when_pressed = bucket_tipped
```

---/hint---
---/hints---

Now that you can count bucket tips, you need to convert this into a height of water that equals the amount of rain that has fallen.  

- Modify your code to print the height of rain that has fallen each time the bucket tips.

---hints---
---hint---
You need to know how much rain causes your gauge's bucket to tip. In the case of the recommended sensor, this is 0.2794 mm. You could use a variable to store this value.

---/hint---
---hint---

Multiply the number of tips by the amount of rain necessary for a bucket tip.

---/hint---
---hint---
Your program could look like this.

```python
from gpiozero import Button

rain_sensor = Button(6)
BUCKET_SIZE = 0.2794
count = 0

def bucket_tipped():
    global count
    count = count + 1
    print (count * BUCKET_SIZE)

rain_sensor.when_pressed = bucket_tipped
```

---/hint---
---/hints---

- Finally, add a function `reset_rainfall` to reset the count of bucket tips so that it starts at `0` again. You will need this function for your fully operational weather station in the next step.

---hints---
---hint---
You can define a function called `reset_rainfall` with the following code:

```python
def reset_rainfall()
```

---/hint---
---hint---

Inside this function, you can set the `count` variable to `0`.

---/hint---
---hint---
Your program could look like this:

```python
from gpiozero import Button

rain_sensor = Button(6)
BUCKET_SIZE = 0.2794
count = 0

def bucket_tipped():
    global count
    count = count + 1
    print (count * BUCKET_SIZE)

def reset_rainfall():
    global count
    count = 0

rain_sensor.when_pressed = bucket_tipped
```

---/hint---
---/hints---

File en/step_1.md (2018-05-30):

## Introduction

In 2016 we sent out nearly 1000 Oracle Raspberry Pi Weather Stations to schools from around the world who had applied to receive these kits. The original Weather Station kit is a HAT for the Raspberry Pi that allows it to collect weather data using a variety of sensors. It is designed to be used in schools to enable students to create their own weather station, and has a range of resources to support its use.

These kits have been very popular. If you're one of the many people who has been wanting to get hold of one, this guide will take you through the process of building your own.

This is an advanced project both in terms of electronics and programming. You should read through the whole project before purchasing any components. 

### What you will make

A weather station for collecting local climate and environmental data. First of all you will develop and build a prototype weather station using a breadboard and jumper wires. Once you've got everything running and tested, you can turn this prototype into a more robust build so that you can deploy it outside and it will be reliable in the long term.

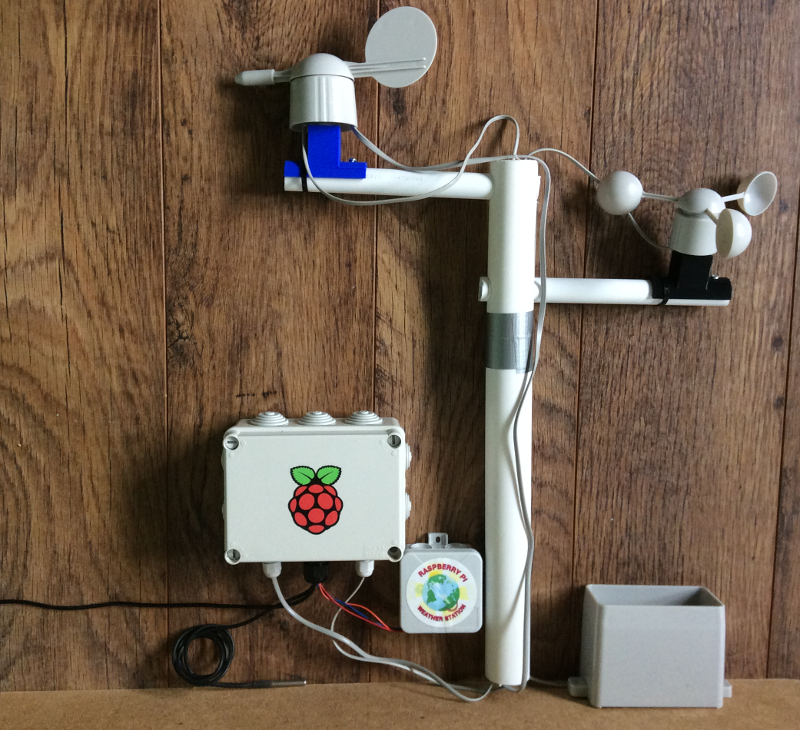
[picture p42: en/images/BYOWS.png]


### What you will learn

This project covers elements from the following strands of the [Raspberry Pi Digital Making Curriculum](http://rpf.io/curriculum):

+ [Use manufacturing techniques and tools to create a completed product](https://curriculum.raspberrypi.org/manufacture/developer/)

+ [Process input data to monitor or react to the environment](https://curriculum.raspberrypi.org/physical-computing/developer/)

+ [Apply abstraction and decomposition to solve more complex problems](https://curriculum.raspberrypi.org/programming/developer/)

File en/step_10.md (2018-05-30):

## Fully functional weather station

Now that you've tested all the sensors individually, it's time to set up the software so that you have a complete data collection system.

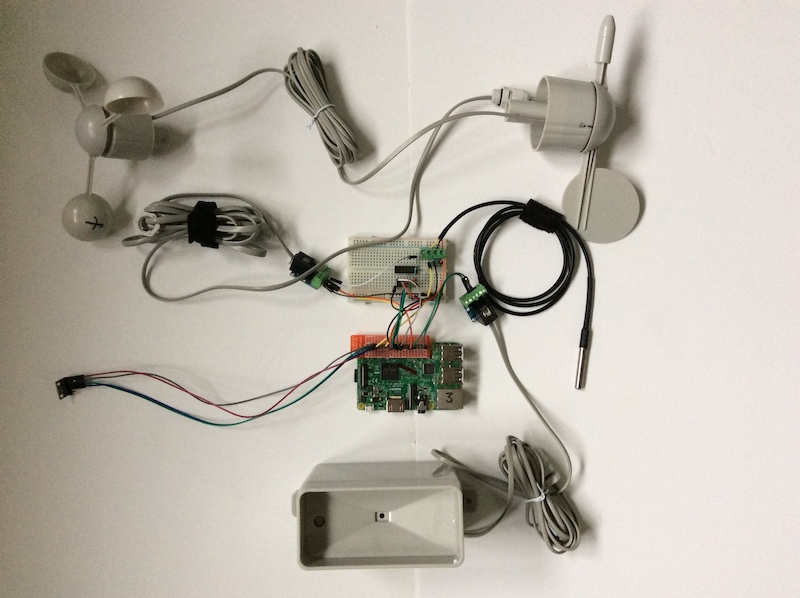
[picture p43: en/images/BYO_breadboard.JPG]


The original Oracle Raspberry Pi Weather Station uses a Unix daemon approach to running the software, and the GPIO connections you've been using so far match those expected by this software. Therefore, you can adapt that code to run your custom build by only making slight modifications. In fact, you've already used the original Oracle Weather Station code for the DS18B20 digital thermal probe.

To complete your custom weather station, you can also adapt and integrate the code you've written for testing to regularly measure and record data.

### Wind speed, gusts and direction

The code you wrote for wind speed and gust measurement will form the basis of your overall weather station software.

+ Make a copy of your `wind.py` script and call it `weather_station_BYO.py` (you can can do this in IDLE by opening `wind.py` and then clicking **Save as**).

You will need to add some additional libraries and some of the Oracle Weather Station code along with programs you've already written.

+ The top of your script should have the following `import` statements:

```python
from gpiozero import Button
import time
import math
import bme280_sensor
import wind_direction_byo
import statistics
import ds18b20_therm

```
As it currently stands, your code will continually record the wind speed every five seconds, keeping track of the largest measurement (gusts) and calculating the mean speed. You can extend this to also simultaneously measure wind direction.

- Modify your code so that instead of pausing for five seconds in each loop, the program takes five seconds worth of wind direction measurements.

---hints---
---hint---
You can use the same `time.time()` method to create a second sub-loop inside the first. Make sure you use a different variable name to store the starting time.
---/hint---
---hint---
You can also use a list to store the wind direction readings, just as you did for the wind speeds.
```python
store_directions = []
```
---/hint---
---hint---
Your modified function could look like the following. You can use the `get_average` function you wrote to calculate the average wind direction based on the list of measurements.

```python
while True:
    start_time = time.time()
    while time.time() - start_time <= wind_interval:
        wind_start_time = time.time()
        reset_wind()
        #time.sleep(wind_interval)
        while time.time() - wind_start_time <= wind_interval:
                store_directions.append(wind_direction_byo.get_value())

        final_speed = calculate_speed(wind_interval)
        store_speeds.append(final_speed)
    wind_average = wind_direction_byo.get_average(store_directions)

    wind_gust = max(store_speeds)
    wind_speed = statistics.mean(store_speeds)
    print(wind_speed, wind_gust, wind_average)
```
---/hint---
---/hints---

- Test your code by spinning the anemometer and wind vane. Does the program produce sensible values?

Right now your program is constantly updating the mean values and peak wind speed as new measurements are made. Your weather station should start afresh with each five seconds of measurement.

+ Add two lines to your code to empty the lists that hold the wind speeds and directions after every pass through the loop.

---hints---
---hint---
You need to empty the `store_speeds` and `store_directions` lists.
---/hint---
---hint---
You can do this with the lines:
```python
store_speeds = []
store_directions =[]
```
---/hint---
---hint---
Your modified function could look like this:

```python
while True:
    start_time = time.time()
    while time.time() - start_time <= wind_interval:
        wind_start_time = time.time()
        reset_wind()
        #time.sleep(wind_interval)
        while time.time() - wind_start_time <= wind_interval:
                store_directions.append(wind_direction_byo.get_value())

        final_speed = calculate_speed(wind_interval)
        store_speeds.append(final_speed)
    wind_average = wind_direction_byo.get_average(store_directions)

    wind_gust = max(store_speeds)
    wind_speed = statistics.mean(store_speeds)
    print(wind_speed, wind_gust, wind_average)
    store_speeds = []
    store_directions =[]
```
---/hint---
---/hints---

- Test your code again.

You should see that you are recording the angular position of the wind vane, and counting the rotations of the anemometer for five seconds. Your code then calculates the mean wind speed and average position of the vane for that period. You will have also noticed that the value for `wind_gust` is now always the same as the mean, because you are emptying the list of speeds after every five-second period — so there is only ever one value (the last one).

Five seconds is a nice sample period, but is too frequent if you want to **store** new measurements. To keep a permanent record, a better period of measurement would be every 5 **minutes**. You can collect five minutes worth of readings, and then record the peak value (gust) from that collection of measurements. That is much more useful!

- Modify the code so that it uses a a sampling frequency of five seconds for its readings, and then calculates new mean speeds and wind directions and records the strongest gust every five minutes.

---hints---
---hint---
You should change the period of the outer-most timed loop to be 5 minutes.
---/hint---
---hint---
Create another variable called `interval` outside the main (`while True`) loop:
```python
interval = 300
```
5 * 60 seconds = 300
---/hint---
---hint---
Then use that as the timing comparison for the outer timed loop:

```python
while True:
    start_time = time.time()
    while time.time() - start_time <= interval:
        wind_start_time = time.time()
        reset_wind()
        #time.sleep(wind_interval)
        while time.time() - wind_start_time <= wind_interval:
                store_directions.append(wind_direction_byo.get_value())

        final_speed = calculate_speed(wind_interval)
        store_speeds.append(final_speed)
    wind_average = wind_direction_byo.get_average(store_directions)

    wind_gust = max(store_speeds)
    wind_speed = statistics.mean(store_speeds)
    print(wind_speed, wind_gust, wind_average)
    store_speeds = []
    store_directions =[]
```
---/hint---
---/hints---
- Test your code. It should now report readings every five minutes. Simulate some wind activity by rotating the vane and anemometer and check that your measurements are what you'd expect.

Now you can add the other sensors into this five-minute loop!

### Rainfall

Integrate the code your wrote for measuring rainfall in `rainfall.py` into your `weather_station_BYO.py` program so that rainfall is measured for five-minute periods and then the count reset.

- Add the bucket size constant definition to the list of other similar variables after the `import` statements.

```python
BUCKET_SIZE = 0.2794
```

- Add these lines before the `while True:` loop.

```python

def bucket_tipped():
    global rain_count
    rain_count = rain_count + 1
    #print (rain_count * BUCKET_SIZE)

def reset_rainfall():
    global rain_count
    rain_count = 0

rain_sensor = Button(6)
rain_sensor.when_pressed = bucket_tipped
```    

Then, after the lines that calculate the wind gusts and speed, add this code:

```python
rainfall = rain_count * BUCKET_SIZE
reset_rainfall()
```

### Temperature, pressure and humidity

When you wrote the code for the BME280 pressure, temperature, and humidity sensor, you created a `read_all` function to return all three measurements. You can call this function from within `weather_station_BYO.py` as you've included your `bme280_sensor` program as an imported library.

- Modify your code so that the readings from the BME280 sensor are also recorded every five minutes.

---hints---
---hint---
You can call the `read_all` function that you wrote earlier.
---/hint---
---hint---
```python
humidity, pressure, ambient_temp = bme280_sensor.read_all()
```
---/hint---
---hint---
Your completed loop code for making measurements should look like this:

```python
while True:
    start_time = time.time()
    while time.time() - start_time <= interval:
        wind_start_time = time.time()
        reset_wind()
        #time.sleep(wind_interval)
        while time.time() - wind_start_time <= wind_interval:
                store_directions.append(wind_direction_byo.get_value())

        final_speed = calculate_speed(wind_interval)
        store_speeds.append(final_speed)
    wind_average = wind_direction_byo.get_average(store_directions)
    wind_gust = max(store_speeds)
    wind_speed = statistics.mean(store_speeds)
    rainfall = rain_count * BUCKET_SIZE
    reset_rainfall()
    humidity, pressure, ambient_temp = bme280_sensor.read_all()
    print(wind_speed, wind_gust, rainfall, wind_average, humidity, pressure, ambient_temp)
    store_speeds = []
    store_directions =[]
```
---/hint---
---/hints---

- Test your code. Exhale onto the BME280 and check that the readings change appropriately.

### Ground temperature

- Now do the same thing for the ground temperature probe. Modify your code so that readings are collected every five minutes.

---hints---
---hint---
You will need to initialise the sensor first:

```python
temp_probe = ds18b20_therm.DS18B20()
```
---/hint---

---hint---
You can use the `read_temp()` function.
---/hint---

---hint---
Your completed code should look like this:

```python
from gpiozero import Button
import time
import math
import bme280_sensor
import wind_direction_byo
import statistics
import ds18b20_therm
import database

wind_count = 0       # Counts how many half-rotations
radius_cm = 9.0 # Radius of your anemometer
wind_interval = 5 # How often (secs) to sample speed
interval =  5 # measurements recorded every 5 minutes
CM_IN_A_KM = 100000.0
SECS_IN_AN_HOUR = 3600
ADJUSTMENT = 1.18
BUCKET_SIZE = 0.2794
rain_count = 0
gust = 0
store_speeds = []
store_directions = []

# Every half-rotation, add 1 to count
def spin():
	global wind_count
	wind_count = wind_count + 1
	#print( wind_count )

def calculate_speed(time_sec):
        global wind_count
        global gust
        circumference_cm = (2 * math.pi) * radius_cm
        rotations = wind_count / 2.0

        # Calculate distance travelled by a cup in km
        dist_km = (circumference_cm * rotations) / CM_IN_A_KM

        # Speed = distance / time
        km_per_sec = dist_km / time_sec
        km_per_hour = km_per_sec * SECS_IN_AN_HOUR

        # Calculate speed
        final_speed = km_per_hour * ADJUSTMENT

        return final_speed

def bucket_tipped():
    global rain_count
    rain_count = rain_count + 1
    #print (rain_count * BUCKET_SIZE)

def reset_rainfall():
    global rain_count
    rain_count = 0

def reset_wind():
    global wind_count
    wind_count = 0

def reset_gust():
    global gust
    gust = 0

wind_speed_sensor = Button(5)
wind_speed_sensor.when_activated = spin
temp_probe = ds18b20_therm.DS18B20()

while True:
    start_time = time.time()
    while time.time() - start_time <= interval:
        wind_start_time = time.time()
        reset_wind()
        #time.sleep(wind_interval)
        while time.time() - wind_start_time <= wind_interval:
                store_directions.append(wind_direction_byo.get_value())

        final_speed = calculate_speed(wind_interval)# Add this speed to the list
        store_speeds.append(final_speed)
    wind_average = wind_direction_byo.get_average(store_directions)
    wind_gust = max(store_speeds)
    wind_speed = statistics.mean(store_speeds)
    rainfall = rain_count * BUCKET_SIZE
    reset_rainfall()
    store_speeds = []
    #print(store_directions)
    store_directions = []
    ground_temp = temp_probe.read_temp()
    humidity, pressure, ambient_temp = bme280_sensor.read_all()

    print(wind_average, wind_speed, wind_gust, rainfall,  humidity, pressure, ambient_temp, ground_temp)

```
---/hint---
---/hints---

## Storing measurements in a database

One of the best ways to store your weather data is in a database. Databases can store very large numbers of records efficiently and make it easier to sort, search, and analyse your data.

There are many different pieces of database software, and MariaDB is a good, versatile general-purpose product. You should have already installed it — if not, head back to the _What you will need_ section and follow the instructions there.

Now to configure the database.

- The database server will already be running. To connect to it, open a terminal window and type:

```bash
sudo mysql
```

You should then see that the command line prompt changes to be `MariaDB [(none)]>`. Type the configuration commands at this prompt.

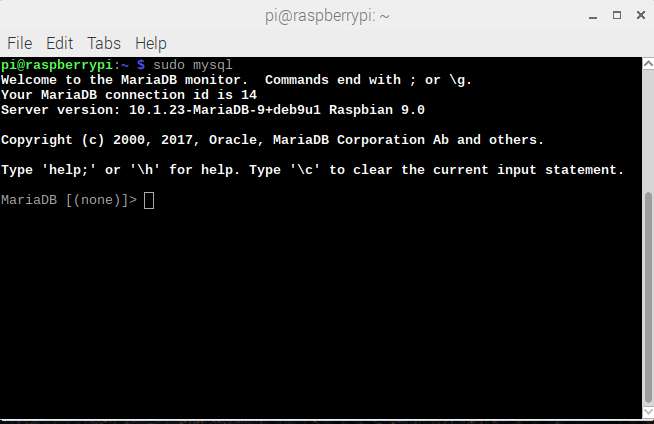
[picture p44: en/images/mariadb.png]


- First create a user and a password. You can choose whatever username you want, but make sure it has a strong password and that you remember the password you set.

```SQL
create user pi IDENTIFIED by 'my54cr4t';
```
The command above will create a user named `pi` with the password `my54cr4t`.  

- Assign all permissions to this user.
```SQL
grant all privileges on *.* to 'pi' with grant option;
```

Remember to change `pi` to whatever username you created in the previous step.

- You can have more than one database on a server. Create one called `weather` to hold your data:

```SQL
create database weather;
```

- Your database should have a table called `WEATHER_MEASUREMENT` that will hold all of your records. First, select the weather database as the place where this table will be stored:

```SQL
use weather;
```
You should now see the prompt change to `MariaDB [weather]>`.

- Create the `WEATHER_MEASUREMENT` table with fields to hold your weather data.

```SQL
CREATE TABLE WEATHER_MEASUREMENT(
ID BIGINT NOT NULL AUTO_INCREMENT,
REMOTE_ID BIGINT,
AMBIENT_TEMPERATURE DECIMAL(6,2) NOT NULL,
GROUND_TEMPERATURE DECIMAL(6,2) NOT NULL,
AIR_QUALITY DECIMAL(6,2) NOT NULL,
AIR_PRESSURE DECIMAL(6,2) NOT NULL,
HUMIDITY DECIMAL(6,2) NOT NULL,
WIND_DIRECTION DECIMAL(6,2) NULL,
WIND_SPEED DECIMAL(6,2) NOT NULL,
WIND_GUST_SPEED DECIMAL(6,2) NOT NULL,
RAINFALL DECIMAL (6,2) NOT NULL,
CREATED TIMESTAMP NOT NULL DEFAULT CURRENT_TIMESTAMP,
PRIMARY KEY ( ID )
);
```
Now you can modify your `weather_station_BYO.py` program to record data in this database. Once again you can use code from the Oracle Raspberry Pi Weather Station software.

- Add this line to the top of `weather_station_BYO.py`:

```python
import database
```
- Just before the main `while True` loop, add this line to connect your code to the MariaDB database:

```python
db = database.weather_database()
```
- Then finally, below the line in the main `while True` loop that prints your data readings, add this line to insert a row of records into the database:

```python
db.insert(ambient_temp, ground_temp, 0, pressure, humidity, wind_average, wind_speed, wind_gust, rainfall)
```

- Save your code. Now using nano or another text editor, modify the `/home/pi/weather-station/credentials.mysql` file so that it contains the username and password you created for your MariaDB database.

 ```json
 {
"HOST": "localhost",
"USERNAME": "pi",
"PASSWORD": "my54cr4t",
"DATABASE": "weather"
}
 ```

## Test your `weather_station_BYO.py` program

You may see warning messages about truncated values, but these can be safely ignored.

- Run the code for a while to allow it to record several values (you can always adjust the value of the variable `interval` to a smaller number if you're impatient and don't want to wait five minutes in between each iteration).

- Check that no errors are produced (except for the warnings about truncated values, which you can ignore).

- Open a terminal window and connect the the MariaDB database:

```bash
sudo mysql
```
- Select the `weather` database:

```SQL
 use weather;
 ```

 - Then run this SQL query, which will tell you how many rows are in the `WEATHER_MEASUREMENT` table:

 ```SQL
 select count(*) from WEATHER_MEASUREMENT;
 ```

This should display a number that matches the number of times your code has recorded a weather data measurement.

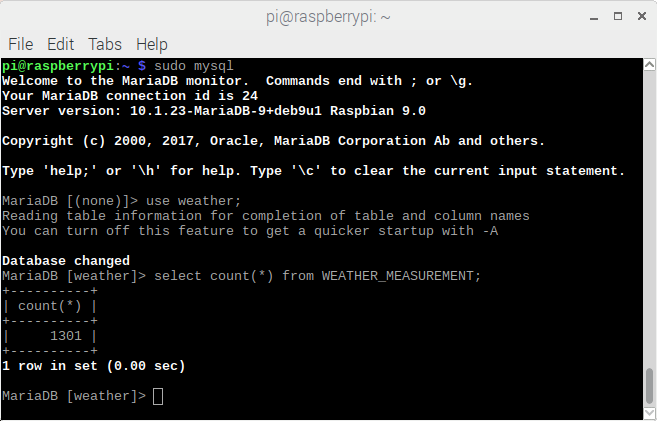
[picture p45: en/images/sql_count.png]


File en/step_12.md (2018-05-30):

## Keeping your weather station dry

This is really important. If the Pi or any of the electronics gets wet or even very damp, they will fail or start to corrode. The Oracle Raspberry Pi Weather Station uses a small weatherproof enclosure to house the external environmental sensors. The key idea is to allow outside air to flow around the sensors but to prevent moisture from reaching them.

### Weatherproof boxes

- Find two waterproof enclosures, one larger one for the Pi and the breadboard or HAT, and another smaller one for the BME280 sensor. The larger box should have a couple of holes for the RJ11 cables connecting the wind and rain sensors, and for some long wires to the BME280.

- Most commercial enclosures will have holes for routing cables, some with grommets that help keep out moisture. Alternatively, you can cut or drill your own holes and use grommets and sealing glands around the cables.

- If you're using the recommended enclosures as listed in the _What you will need_ section, then you can use [this 3D-printable mount to secure the Raspberry Pi inside the larger box](resources/BYOWS-bracket.stl){:target="_blank"}. and [this one to hold BME280 sensor into the smaller one](resources/bme280holder.stl){:target="_blank"}.. The BME280 bracket should just slot in.



- Use short self-tapping screws to secure the mounts into the holes and/or grooves at the back of the larger box.



- In oder to get representative readings for ambient temperature and humidity, air needs to circulate around the BME280 sensor. Remove both hole covers from one side of the smaller box. You can then pass the wires for the sensor up through one hole. Make sure you mount this box outside with the holes are facing downwards so that rain cannot enter this way.



- Use waterproof nylon cable glands to prevent moisture entering the enclosure through the holes used for the cables. If the glands don't fit snugly around the cables, you could 3D print some grommets or wrap electrical tape around the cable to make a tighter seal.

- The larger recommended enclosure has holes on all four sides that are sealed with rubber plugs. Use three of these holes along the bottom of the box to provide an escape route for your cables. Use a M16 cable gland in each of the two outer holes and pass the cable for the rain gauge through one and the cable for the wind sensors through the other.

- If you're using the Ethernet cable to provide wired network access for your weather station, you may need to use a larger gland or an extra one of the holes in the enclosure.



- Then use the larger M20 gland for the centre hole and feed the power cable, DS18B20 probe, and the wires for the BME280 sensor through.



- The hole in the M20 is quite large, so you should pad the cables to ensure a tight fit (if you use a smaller gland, then the micro USB connector for the power cable would not be able to pass through). A 3D-printable grommet is available [here](resources/BYOWS-grom.stl){:target="_blank"}. — use two rotated at 180 degrees to each other so that there is no gap all the way through.

- The larger box can be installed inside, making it much easier to keep it dry, and allowing easier connection to power and networking. However, the various cables for the external sensors (rain gauge, wind vane, anemometer, and BME280) all need to be routed inside so this may involve a bigger hole in an external wall. Mounting everything outside means you only have to supply power to the weather station (assuming you are using wireless connectivity for data transfer).

Now you're ready to install your weather station outside. You could mount your station on a wall, rooftop, fence, or even on a plumbing pipe stuck in the ground. As long as the sensors are open to the elements, any location is fine. Don't forget:

- The rain gauge needs to collect rain
- The anemometer and wind vane need to be in the wind
- The smaller BME280 box needs to breathe — try to avoid situating it in direct sunlight
- The weather station needs to be connected to power, and to a network (wirelessly or via an Ethernet cable)

It is not possible to provide specific instructions for mounting your station, as the exact method will depend on your particular location and environment. However, here are some tips for a couple of aspects of the process that should help you get started:

+ [Installing your Weather Station outside: wind sensors](https://www.raspberrypi.org/learning/weather-station-guide/outside1.md)

+ [Installing your Weather Station outside: connecting to WiFi](https://www.raspberrypi.org/learning/weather-station-guide/outside2.md)

You may not be able to find an ideal location. Perhaps trees block the wind, or the rain gauge is partially sheltered by an overhang. Don't worry, just install your weather station anyway! You could even use this as a learning opportunity: for example, would it be possible to take reduced rain readings into account automatically? If airflow around the BME280 is limited, could you add in a small fan?

## Share your design

Now that you've built your own weather station, why not share your design and installation with the community? If you've used different sensors or chosen another circuit layout, please post the details on the [Weather Station forum](https://www.raspberrypi.org/forums/viewforum.php?f=112&sid=e893b51c323da761164dc232a929f962). We always love to see photos of weather station builds, and we might even feature them on our blog on in weather station newsletters.

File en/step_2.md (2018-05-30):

## What you will need

There are many different sensors available that you could use to make weather measurements. You don't have to use the exact same hardware that is described here to build your weather station, but if you choose different components, you will probably need to also find (or write) a Python library that works with them.

The specific sensors and components here were chosen after considering a number of factors:
- Availability
- Cost
- Linux/Python support
- Reliability
- Accuracy
- Ease of use

This does not mean that the components chosen are the cheapest, most accurate, and easiest to use. Rather they are balanced for all these factors. For example, in some cases accuracy has been sacrificed in favour of ease of use.

When selecting the components for your weather station, you should make choices based on what is most important for your particular project. We always like to hear about alternative builds, so please post your designs in the [Weather station forum](https://www.raspberrypi.org/forums/viewforum.php?f=112&sid=fd0218c9a5c6ff4445eb618f3b0a6eca){:target="_blank"}.

### Hardware

+ A Raspberry Pi, either one that has built-in wireless connectivity or has a a WiFi dongle
+ A BME280 pressure, temperature, and humidity sensor
+ A DS18B20 digital thermal probe (with 1m lead)
+ Two 4.7 KOhm resistors
+ Some 5mm-pitch PCB mount screw terminal blocks
+ A breadboard, some jumper wires
+ [An anemometer, wind vane, and rain gauge](https://www.argentdata.com/catalog/product_info.php?products_id=145){:target="_blank"}
+ Two RJ11 breakout boards (optional)
+ A MCP3008 analogue-to-digital convertor integrated circuit
+ Weatherproof enclosures; recommended products are this [75x75x37mm](http://cpc.farnell.com/spelsberg/332-907/universal-junc-box-7-entry/dp/EN81013){:target="_blank"} box for the BME280 and this larger [150x110x70mm](http://cpc.farnell.com/olan/ol20112/box-ip55-glanded-150x110x70mm/dp/EN82191){:target="_blank"} box for the Pi and a soldered HAT; if you're sticking with a less durable breadboard-only solution, then you may need a larger enclosure such as this [190x140x70mm one](http://cpc.farnell.com/olan/ol20013/box-ip55-glanded-190x140x70mm/dp/EN82192){:target="_blank"}

### Software

+ The Oracle Raspberry Pi Weather Station software. You don't need to install it, but you'll use some of the Python programs. Clone the GitHub repository by opening a Terminal window and typing:
```bash
git clone https://github.com/RaspberryPiFoundation/weather-station
```

+ The BME280 Python library:
```bash
sudo pip3 install RPi.bme280
```
+ The MariaDB database server software:
```bash
sudo apt-get install -y mariadb-server mariadb-client libmariadbclient-dev
sudo pip3 install mysqlclient
```

### Additional resources

If you are going to construct a permanent Weather HAT for your Pi, you may also need:
+ A soldering iron, solder, and safety equipment
+ Solid core wire (22 AWG)
+ An [Adafruit Perma-Proto HAT for Pi Mini Kit](https://www.adafruit.com/product/2310){:target="_blank"}
+ A 16-pin DIL/DIP IC Socket
+ Two 2-pin male headers
+ General prototyping tools: side-cutters, wire strippers. screwdrivers, etc.
+ Insulating tape
+ Access to a 3D printer or 3D printing service for these parts: [a mount to secure the Raspberry Pi inside the larger box](resources/BYOWS-bracket.stl){:target="_blank"}. and a [bracket to hold BME280 sensor into the smaller one](resources/bme280holder.stl){:target="_blank"}.

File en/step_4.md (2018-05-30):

## Air quality

The original Oracle Raspberry Pi Weather Station kit used a Figaro TGS2600 sensor for air quality measurements. The batch of devices installed on the Weather Station HAT have worked well, but we've noticed that many of the ones we've tested recently have been very difficult to calibrate and have produced contradictory readings. They're fine if you want to detect a general change in the local gases (for example to build a [fart detector](https://projects.raspberrypi.org/en/projects/fart-detector){:target="_blank"}), but we do not currently recommend them for use in a custom weather station.

We are continuing to evaluate low-cost air quality sensors and will update this guide as soon as we find one we're happy with.

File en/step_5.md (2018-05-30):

## Active mechanical sensors

So far, all the sensors you've used have been passive electronic sensors that just sit there and make measurements of their surroundings. However, to measure things like rainfall and wind speed/direction, you'll need to use active mechanical devices that physically interact with the environment.

The original Oracle Weather Station kit used popular [wind and rain sensors](https://www.argentdata.com/catalog/product_info.php?products_id=145){:target="_blank"} that are used in many consumer weather stations. These are the recommended sensors to use, as they are robust and reliable. Their [data sheet](https://www.argentdata.com/files/80422_datasheet.pdf){:target="_blank"} gives more information about the sensors' size and construction.

### Connectors

These sensors usually come with RJ11 connectors (they look like a standard telephone jack), which are sturdy and therefore difficult to accidentally dislodge, so your weather station will remain operational even in blustery conditions.

When it comes to connecting them to your Pi, you have three options:
1. Chop off the male RJ11 connectors and connect the wires using screw terminals or by soldering.
1. Use female RJ11 connectors — these are quite fiddly to use with breadboards, but can provide a very sturdy connection if used with a printed circuit board (PCB) as part of a permanent weather station.
1. Use RJ11 breakout boards:

+ These can be really helpful for prototyping, but the larger ones can be too bulky for long-term deployment.



+ Smaller ones often come with solderable pins that can be used with stripboard or a prototyping HAT to make a durable connection. In the coming steps the assembly instructions for creating a permanent hardware solution will use these smaller breakout boards.



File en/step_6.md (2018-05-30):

## Wind speed

A typical anemometer has three arms with scoops on the end that catch the wind and cause the arms to spin. If you were to dismantle one of the anemometers used by the original Oracle Weather Stations, you would find a small magnet attached to the underside.  



At two points of the magnet's rotation, it triggers a clever piece of electronics called a **reed switch**, pictured below.



The reed switch has two metal contacts inside it that contact each other when under the influence of a magnet. Therefore, electronically, this switch works in exactly the same way as a button connected to the Raspberry Pi: when the anemometer spins, its magnet passes the reed switch, causing it to form a closed circuit momentarily. Therefore, you can use the number of signals from the reed switch to calculate how fast the anemometer spins.

Whenever the reed switch is triggered, it produces a signal you can detect via a GPIO pin. For each full rotation of the anemometer, the sensor will produce two detectable signals. By counting and timing these signals, you can calculate the speed of the wind.



There are many ways of doing this with Python. One approach is to treat the sensor like a button and then use the `gpiozero` library to count the number of times it has been 'pressed'.

- Consumer anemometers normally have two wires. Connect one to a **ground** pin and the other to **GPIO 5**. If you're using the RJ11 connectors, the anemometer uses the middle two wires of the cable, which are normally pins 3 and 4 on RJ11 breakout boards.



 With the anemometer added, your circuit should look like this:



- Open IDLE, create a new Python file, and save it as `/home/pi/weather-station/wind.py`.
- Add the lines below to use GPIOzero's `Button` functions and set up a Button on **GPIO 5**. Also create a variable called `wind_count` to store the number of rotations.

```python
from gpiozero import Button

wind_speed_sensor = Button(5)
wind_count = 0
```

- Now define a function that will be run whenever the pin is activated by a spin of the anemometer.

```python
def spin():
    global wind_count
    wind_count = wind_count + 1
    print("spin" + str(wind_count))

wind_speed_sensor.when_pressed = spin
```

- Save and run your code. Test it by manually turning the arms of the anemometer. In the Python shell, you should see your code being triggered and the count variable incrementing twice very rotation.



Now you can count the signals from the anemometer, you can use this data to calculate the wind speed.

### Calculating wind speed

The anemometer produces two signals per spin, so you can count the number of full rotations of the sensor by halving the number of detected inputs. This can then be used to calculate the wind speed:

**speed = distance / time**

To calculate **speed**, you need to know the **distance** travelled in a certain amount of **time**. Measuring time is fairly straightforward, and you can count the number of signals over the course of a fixed time period, for example five seconds.

The distance travelled by one of the cups will be equal to the number of rotations multiplied by the distance around the edge of the circle (circumference):

**speed = (rotations * circumference) / time**

The circumference can be calculated as long as you know either the **radius** or **diameter** of the circle.



You can discover the radius of the circle made by the anemometer by measuring the distance from the centre to the edge of one of the cups. Once you know the radius, you can find the circumference with the formula **2 * pi * radius**. Don't forget that a whole rotation generates two signals, so you'll need to halve the number of signals detected:

**speed = ( (signals/2) * (2 * pi * radius) ) / time**

The radius for the recommended anemometers used by the original Oracle Weather Station is 9.0cm, and that is the figure that will be used in the code examples that follow. Don't forget to change this value if your anemometer has different dimensions!

To implement this formula in Python, you can use the `math` library. For example, if you measured 17 signals from your anemometer in 5 seconds, your wind speed could be calculated like this:

```python
import math

radius_cm = 9.0
wind_interval = 5
wind_count = 17

circumference_cm = (2 * math.pi) * radius_cm
rotations = count / 2.0
dist_cm = circumference_cm * rotations
speed = dist_cm / wind_interval

print(speed)
```
- Remove (or comment out) the line in the `spin` function that prints out the `wind_count` value.

- Now use this formula to modify your `wind.py` code so that it also calculates the speed of the wind in centimetres per second (cm/s).

---hints---
---hint---
First, import the `math` and `time` libraries and set some variables to hold the radius of your anemometer and the time interval for measurements.

```python
import time
import math
radius_cm = 9.0 # Radius of your anemometer
wind_interval = 5    # How often (secs) to report speed
```

---/hint---
---hint---
Then create a new function to handle the calculation. This should take the time period of the measurement (in seconds) as an input and use the formula above to work out the speed.

```python
def calculate_speed(time_sec):
        global wind_count  
        circumference_cm = (2 * math.pi) * radius_cm        
        rotations = wind_count / 2.0
        dist_cm = circumference_cm * rotations
        speed = dist_cm / time_sec

        return speed
```

**Note**: you need to declare the `wind_count` variable as global so that it can be accessed from within the function.
---/hint---
---hint---
Finally, add a loop to continually take measurements every five seconds. The complete code might look something like this:

```python
from gpiozero import Button
import time
import math

wind_count = 0       # Counts how many half-rotations
radius_cm = 9.0 # Radius of your anemometer
wind_interval = 5    # How often (secs) to report speed

# Every half-rotation, add 1 to count
def spin():
	global wind_count
	wind_count = wind_count + 1
	# print("spin" + str(wind_count))

# Calculate the wind speed
def calculate_speed(time_sec):
        global wind_count  
        circumference_cm = (2 * math.pi) * radius_cm        
        rotations = wind_count / 2.0

        # Calculate distance travelled by a cup in cm
        dist_cm = circumference_cm * rotations

        speed = dist_cm / time_sec

        return speed

wind_speed_sensor = Button(5)
wind_speed_sensor.when_pressed = spin

# Loop to measure wind speed and report at 5-second intervals
while True:
        wind_count = 0
        time.sleep(wind_interval)
        print( calculate_speed(wind_interval), "cm/h")
```

---/hint---
---/hints---

### Measurement units

Currently, the code calculates the wind speed in cm/s. However, this is not particularly useful — a more practical unit would be kilometres per hour (km/h).

- Modify your code to return the wind speed in km/h.

---hints---
---hint---
In order to convert your units, you'll need to:

+ Convert cm to km by dividing the distance by the number of centimetres in 1 kilometre
+ Convert seconds to hours by multiplying the speed by the number of seconds in 1 hour
---/hint---
---hint---
It's a good idea to set up constants to store the values of the number of seconds in an hour and the number of centimetres in a kilometre. This will make your calculations less confusing for other people to understand.

```python
CM_IN_A_KM = 100000.0
SECS_IN_AN_HOUR = 3600
```
---/hint---
---hint---
Your new `calculate_speed` function should look like this:
```python
def calculate_speed(time_sec):
    global wind_count
    circumference_cm = (2 * math.pi) * radius_cm
    rotations = wind_count / 2.0

    dist_km = (circumference_cm * rotations) / CM_IN_A_KM

    km_per_sec = dist_km / time_sec
    km_per_hour = km_per_sec * SECS_IN_AN_HOUR

    return km_per_hour
```
---/hint---
---/hints---

### Calibration

Most anemometers will have a specification that includes calibration data to help you test the accuracy of your sensor. The [data sheet](https://www.argentdata.com/files/80422_datasheet.pdf){:target="_blank"} for the recommended anemometers says that one rotation a second should equate to 2.4 km/h. So in the example interval of five seconds, five spins (ten signals) should equal the same 2.4 km/h wind speed.

- Run your program and spin the anemometer five times within the first five seconds. What wind speed value is reported?



You'll probably find that the value doesn't match the specification. This loss of accuracy is due to something called the **anemometer factor**, and is a result of some of the wind energy being lost when the arms turn. To compensate for this, you can multiply the reading generated by your program by an adjustment factor.

For the recommended anemometers, this factor equals `1.18`.

-  Update the final line in your `calculate_speed` function to multiply your speed in km/h by `1.18`.

---hints---
---hint---
To make sure your code makes sense to other people, store the anemometer adjustment value as a constant with the value of `1.18`, and then use the constant in your wind speed calculation.

```python
ADJUSTMENT = 1.18
```
---/hint---
---hint---
Your new `calculate_speed` function should look like this:
```python
def calculate_speed(time_sec):
    global wind_count
    circumference_cm = (2 * math.pi) * radius_cm
    rotations = wind_count / 2.0

    dist_km = (circumference_cm * rotations) / CM_IN_A_KM

    km_per_sec = dist_km / time_sec
    km_per_hour = km_per_sec * SECS_IN_AN_HOUR

    return km_per_hour * ADJUSTMENT
```
---/hint---
---/hints---

- You'll need to alter the final `print` line of your code so that it now shows the output in the correct units.
- Re-run the code, and this time you should get a value closer to 2.4 km/h.

- When you assemble the complete weather station, it will be useful to be able to reset your `wind_count` variable to zero, so add a function that does that now:

```python
def reset_wind():
    global wind_count
    wind_count = 0
```

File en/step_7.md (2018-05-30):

## Wind gusts

Weather reports and forecasts will normally report the wind speed along with wind gust information. A wind gust is a brief increase in wind speed that can occur whenever the wind is blowing. Gusts are more noticeable as the wind speed increases. This is because the force exerted by the wind increases rapidly as the wind speed increases.

Gusts normally occur because the air is not able to move along the ground at a constant speed. Obstacles such as vegetation, buildings, and elevation changes causes surface friction, which will slow the wind down in some places more than others. Air closer to the ground suffers from this phenomenon more than air higher up. This creates a more turbulent wind flow along the ground, which leads to gusts. A typical wind gust lasts less than 20 seconds.

### Storing wind readings

When your weather station is fully operational, you can record the maximum wind speed during a given period (the gust) as well as the average speed. You can do this by constantly taking wind speed measurements for five seconds, and temporarily storing them to be processed every few minutes. To do this, we will use a Python data structure called a **list**.

- Open IDLE, and open the file `/home/pi/weather-station/wind.py` file that you created in the last step.

- Add a line at the very top to import the `statistics` library.

```python
import statistics
```

- Then add this line, which creates an empty list called `store_speeds`, below the `import` lines:

```python
store_speeds = []
```

- Now modify the `while True` loop so that it contains a sub-loop that continually takes wind speed readings and adds them to this list. You can then use `statistics.mean` to calculate the mean value of readings in the `store_speeds` list. 

```python
while True:
    start_time = time.time()
    while time.time() - start_time <= wind_interval:
        reset_wind()
        time.sleep(wind_interval)
        final_speed = calculate_speed(wind_interval)
        store_speeds.append(final_speed)

    wind_gust = max(store_speeds)
    wind_speed = statistics.mean(store_speeds)
    print(wind_speed, wind_gust)

```

Notice that we're using `time.time()` to create a variable called `start_time` and then checking when the time has advanced by more than `wind_interval` seconds in the inner `while` loop.

- Run you code. Blow on the anemometer or spin it by hand and watch the readings that are produced.



When you stop spinning, you should see that the second reading remains the same (as this is the peak gust that has been produced), while the average speed falls off over time as the anemometer slows down.

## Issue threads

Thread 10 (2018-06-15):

feedback from projects site

martinohanlon, 2018-06-15:
URL: /en/projects/build-your-own-weather-station The "View project & license on GitHub" on https://projects.raspberrypi.org/en/projects/build-your-own-weather-station links to https://github.com/RaspberryPiLearning/build-your-own-weather-station which doesn't work

martinohanlon, 2018-06-18:
No not normally, I have made it public.

Closed 2018-06-18.

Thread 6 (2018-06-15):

Feedback from project site

martinohanlon, 2018-06-15:
URL: /en/projects/build-your-own-weather-station/ Hi, I'd like to print out the project "Build your own weather station", but all that happens when I press the 'print' button on your page is the browser refreshes to a blank page. Also - If I accidentally go to the 'all projects' list, I can't find the build your own weather station one under either 'weather' or 'python'

MarcScott, 2018-06-28:
I think this might be one for @aldreth

MarcScott, 2018-07-19:
I've shifted this issue to https://github.com/RaspberryPiFoundation/projects-ui/issues/1169 and am now closing

Closed 2018-07-19.

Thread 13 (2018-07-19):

Print doesn't work

martinohanlon, 2018-07-19:
Lots of feedback from the projects site suggest this. Tested myself I just get a blank page when I visit the print page.

MarcScott, 2018-07-19:
Duplicate - I've left an issue on projects-ui - https://github.com/RaspberryPiFoundation/projects-ui/issues/1169

Closed 2018-07-19.

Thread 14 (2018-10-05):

feedback from project site

martinohanlon, 2018-10-05:
The ground link at the bottom left (connecting the RJ11 breakout board for the rain gauge) is incorrectly placed. The rain gauge uses the center 2 pins, 3 and 4. Your wiring has GPIO 6 grounded and the other side of the rain gauge is not connected to anything.

@topshed - did you want to look at this?

topshed, 2018-10-08:
I'll take a look

topshed, 2018-10-09:
yep, this is a mistake. Updated diagrams now live

Closed 2018-10-09.

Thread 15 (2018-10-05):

feedback from projects site

martinohanlon, 2018-10-05:
Hi there, I'm lost for the rainfall part. the first picture final_circuit_strip_bb.png shows that button 6 is connected to on spot on the Adafruit board, and the last picture ada_11.png shows that button 6 is now connected somewhere else. I would appreciate any feedback on this. Many thanks, great project raspproject.20.ericm@neverbox.com

topshed, 2018-11-26:
@raspproject.20.ericm@neverbox.com Thanks for your feedback. Please can you explain what you mean by "button 6"? Do you mean GPIO pin 6? Thanks.

topshed, 2018-11-27:
I've contacted the OP to ask for clarification

topshed, 2018-11-27:
Fixed by previous issue work

Closed 2018-11-27.

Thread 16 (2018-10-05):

feedback from projects site

martinohanlon, 2018-10-05:
Connecting BME280 to GPIO Following the pictures on the pins of GPIO I believe that GND should be connected to pin 9 (GND) instead of pin 6 as showed on the picture in this project. If I am right would you please be so kind to adapt the text? My mailadress is: tphoeksma@zonnet.nl

topshed, 2018-11-26:
Do we know which section of the instructions this refers to, @MarcScott ?

MarcScott, 2018-12-03:
Sorry no. This is just feedback that was left on the Projects site

martinohanlon, 2019-04-12:
Closing - without additional information we cant proceed.

Closed 2019-04-12.

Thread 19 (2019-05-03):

en/solutions missing

raspberrypilearningbot, 2019-05-03:
/learning was expecting a file or directory at en/solutions

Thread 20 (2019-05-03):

en/solutions missing

raspberrypilearningbot, 2019-05-03:
/learning was expecting a file or directory at en/solutions

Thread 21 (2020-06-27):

Confusion with the voltage divider

VicenteYago, 2020-06-27:
Hi, originally I opened a post in the forum, but I decided to expand the content here for convenience, here is the link: https://www.raspberrypi.org/forums/viewtopic.php?f=112&t=278466
I also made feedback submission through the station's own guide, sorry if you receive this problem through various channels.

Let's get to the problem:
In the official guide, concretely in this link: https://projects.raspberrypi.org/en/projects/build-your-own-weather-station/7

the concept of voltage divider is presented, and then the following equation is written:

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

but then, in the clue code it's written like this:
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

Obviously the equations are not equivalent, and according to the literature the correct one is the first.

But, lets go deeper in my confusion: the voltage divider its used to measure the output voltage from the wind vane in order to get an angle that indicates where the wind is coming from, using in the process an analog to digital converter. In the datasheet you can see the following table:
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

In the diagram, the external resistance is R1 (10 k) and the inner variable resistance offered by the  wind vane internals is R2.

Guided by my curiosity i decided to replicate the table output voltage (right column) with this python code  from the file vane_values.py (with the corrected equation in the numerator)

```{python}
resistances = [33000, 6570, 8200, 891,
              1000, 688, 2200, 1410,
              3900, 3140, 16000, 14120,
              120000, 42120, 64900, 21880]

def voltage_divider(r1, r2, vin):
        vout = (vin*r2)/(r1+r2) # in the guide its written: (vin*r1)/(r1+r2)
        return round(vout, 3)

for x in range(len(resistances)):
    print("  5V",resistances[x], voltage_divider(10000,resistances[x], 5.0))
```

```{bash}
  5V 33000 3.837
  5V 6570 1.982
  5V 8200 2.253
  5V 891 0.409
  5V 1000 0.455
  5V 688 0.322
  5V 2200 0.902
  5V 1410 0.618
  5V 3900 1.403
  5V 3140 1.195
  5V 16000 3.077
  5V 14120 2.927
  5V 120000 4.615
  5V 42120 4.041
  5V 64900 4.332
  5V 21880 3.432
```
and the result agrees with the datasheet.

Back to the guide it is justified that for the voltage divider, in the case of the raspberry you have to use vin = 3.3 and R1 = 4.7 kohms, so if we modify the code above accordingly:

```{python}
    print("  3.3V",resistances[x], voltage_divider(4700,resistances[x], 3.3))
```
```{bash}
3.3V 33000 2.889
3.3V 6570 1.924
3.3V 8200 2.098
3.3V 891 0.526
3.3V 1000 0.579
3.3V 688 0.421
3.3V 2200 1.052
3.3V 1410 0.762
3.3V 3900 1.497
3.3V 3140 1.322
3.3V 16000 2.551
3.3V 14120 2.476
3.3V 120000 3.176
3.3V 42120 2.969
3.3V 64900 3.077
3.3V 21880 2.716
```

And we have come to the bottom of the problem: those values are not the ones proposed in the solutions:

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

I have not researched further, but I believe that if I have not mistaken any step, the wind directions measured by this sensor and official code would actually be incorrect, because of the failure of the voltage divider equation.

What do you think about this?
I'm really learning about electronics and I wanted to make sense of what I was doing.

 Thank you very much.

jrcalvert, 2020-08-02:
Hello,
Yes, I came to a similar conclusion just yesterday when trying to get the voltage array values to agree with the guide.
I think it might be that the circuit being used shows the output (input to the ADC) has the resister connecting to Ground and Not 5v, so the voltage divider is the opposite way arount, i.e. R1 = wind-vane, R2 = 4.7K.
I'm not sure, but that's my current reasoning!

Jason

VicenteYago, 2020-08-03:
Yes!, if you switch the resistor values all makes sense.
Thanks for the up, i forgot to update this issue, with this info.

I think this is solved, im closing if nobody opposes.

Closed 2020-08-03.

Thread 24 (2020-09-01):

Expired hardware link (Aug 2020)

libxx1, 2020-09-01:
Under the 'Hardware' section of this page

https://projects.raspberrypi.org/en/projects/build-your-own-weather-station/1

the link to "An anemometer, wind vane, and rain gauge" is no longer current

https://www.argentdata.com/catalog/product_info.php?products_id=145

libxx1, 2020-10-14:
Closing as link is now working and products back in stock.

Closed 2020-10-14.

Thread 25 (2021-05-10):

Wiring diagram incorrect

libxx1, 2021-05-10:
URL: /en/projects/build-your-own-weather-station/8

I think the wiring of the Wind speed and the rainfall sensors are shown wrong in the diagram as they are connected to Ground and not to the 3,3v connection.

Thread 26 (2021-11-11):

Wind direction wiring diagram

wmbbarnett, 2021-11-11:
Need a detail drawing of the wind direction sensor with the MCP3008 ADC and the Raspberry Pi.

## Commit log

2017-10-19 dht22 instructions added
    [dht22.fzz]
2017-10-30 added htu21d and ds18b20 sections
    [ds18b20.fzz, htu21d.fzz]
2017-11-07 swapped to use bme280 for temp & humidity as well as pressure
    [bme280.fzz]
2017-11-08 wind vane
    [MCP3008.fzz, MCP3008_vane.fzz]
2017-11-14 Final parts of wind direction guide
    [MCP3008_vane.fzz]
2017-11-22 revised circuits
    [BYOWeatherHAT.fzz, MCP3008.fzz, MCP3008_vane.fzz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]
2017-11-22 fixed wire issues
    [wind_speed.fzz]
2017-12-06 database instructions
    [final_circuit.fzz, final_circuit_strip.fzz, rainfall.fzz]
2017-12-21 Hrdware contsructions first pass
    [final_circuit_strip.fzz]
2017-12-22 First stages of assembling HAT
    [final_circuit_strip.fzz]
2017-12-22 More steps
    [final_circuit_strip-stages.fzz, final_circuit_strip.fzz]
2018-01-30 Outdoors bits added
    [ada_2.fzz, bme280.fzz, final_circuit_strip.fzz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]
2018-04-27 Updated after testing
    [final_circuit_strip.fzz]
2018-05-14 add in reed switch explanation from step 9
2018-05-15 Added 3D print files
    [BYOWS-bracket.stl, BYOWS-grom.stl, bme280holder.stl]
2018-10-09 Fixed rain gaege wire to Rj11 mistake in diagrams for step 11 (issue #14)
    [final_circuit_strip-stages.fzz]
